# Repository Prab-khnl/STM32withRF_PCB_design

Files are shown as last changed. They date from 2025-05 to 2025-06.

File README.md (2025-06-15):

Chip used :- STM32WB55CEU6.

Important Online Note :-
<https://www.st.com/resource/en/application_note/an5165-how-to-develop-rf-hardware-using-stm32wb-microcontrollers-stmicroelectronics.pdf>

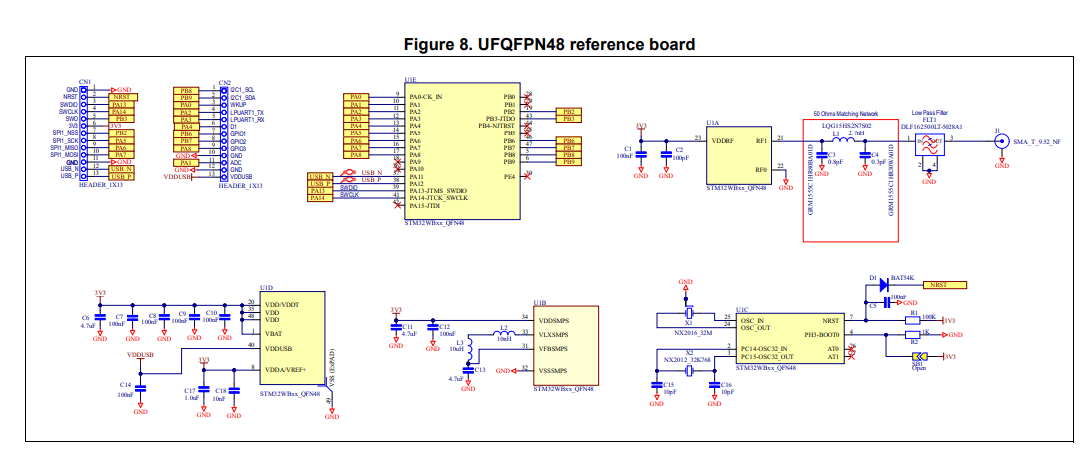
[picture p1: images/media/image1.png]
This is the reference :-

Use STM32CubeIDE to get more information about the Chip :-

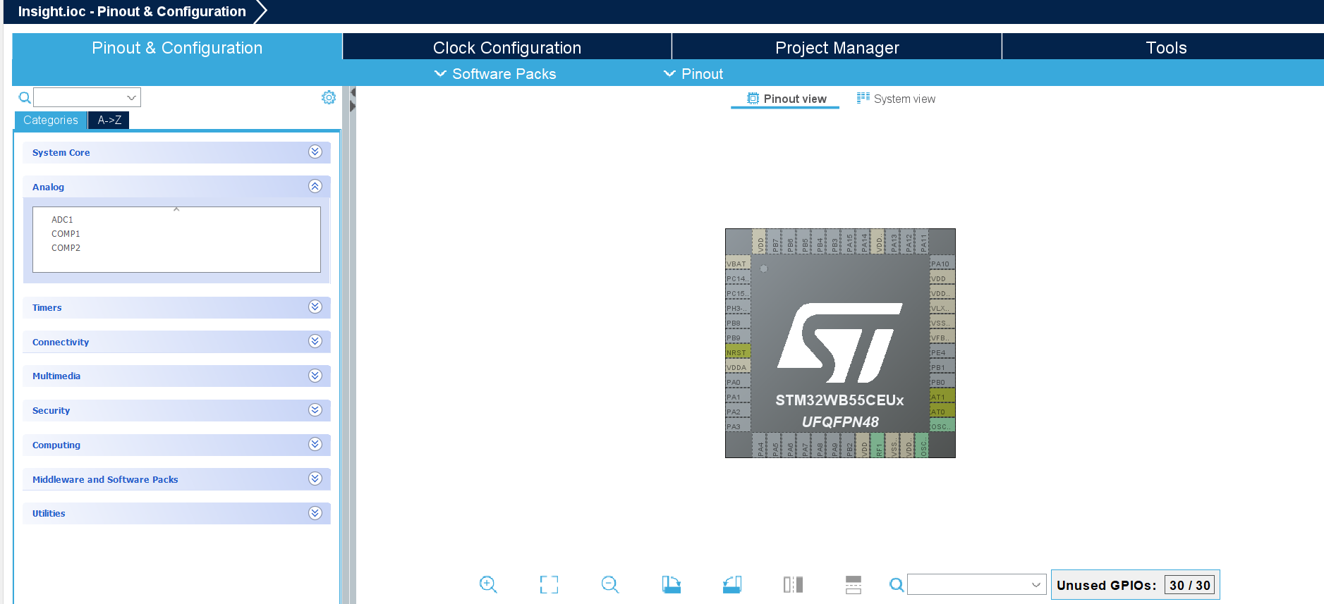
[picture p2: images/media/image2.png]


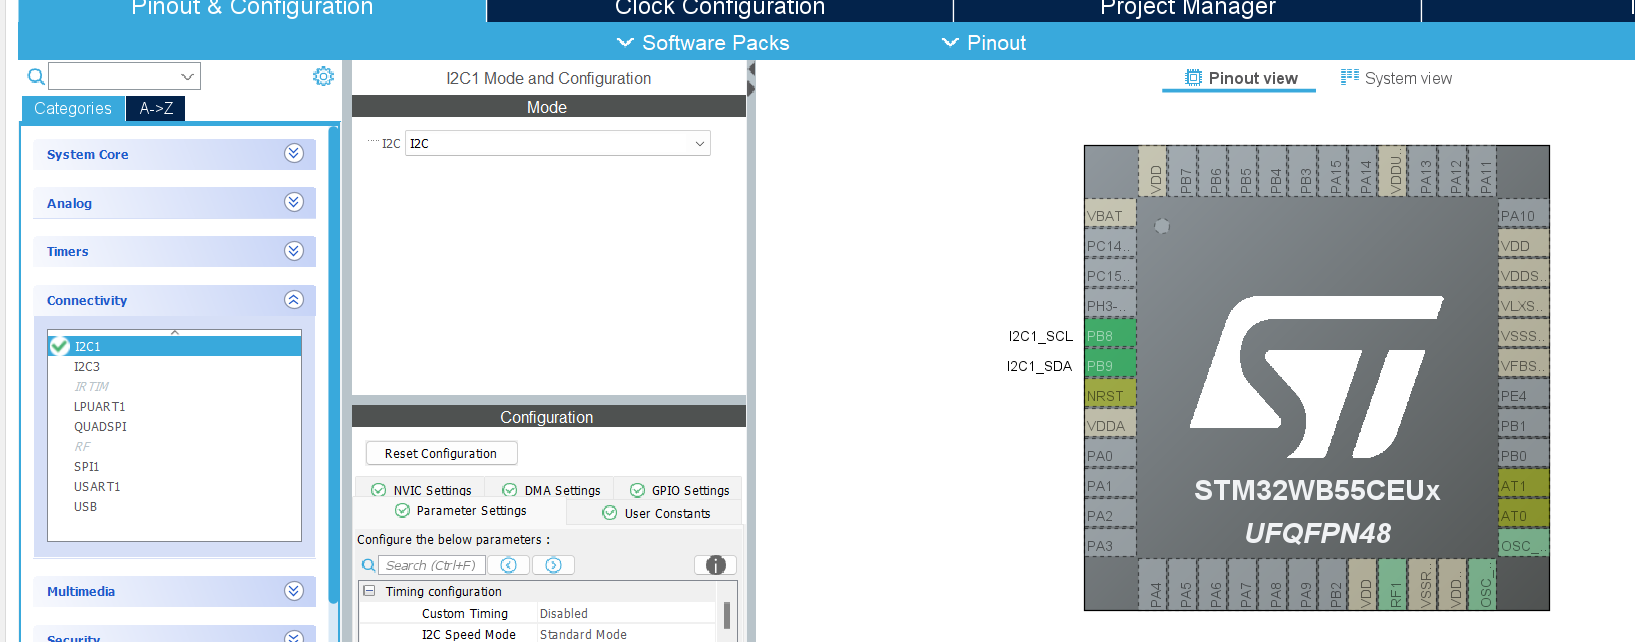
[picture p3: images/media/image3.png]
Here I have enabled I2C on PB8 and PB9
corresponding to Pin 5 and 6 respectively.

In Kicad, import the board STM32WB55CEUX.

Ground the Pins VSS5MP5, VSSRF and VSS.

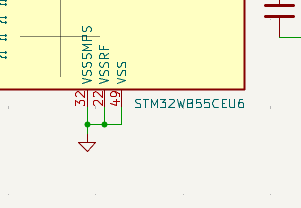
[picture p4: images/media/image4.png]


As illustrated on the reference manual, the Pin VDDUSB, VDDA, VDD, VDD,
VDD and VBAT are connected to 3.3V power supply through bigger capacitor
(4.67uF) and smaller capacitors (100nF : local supply).

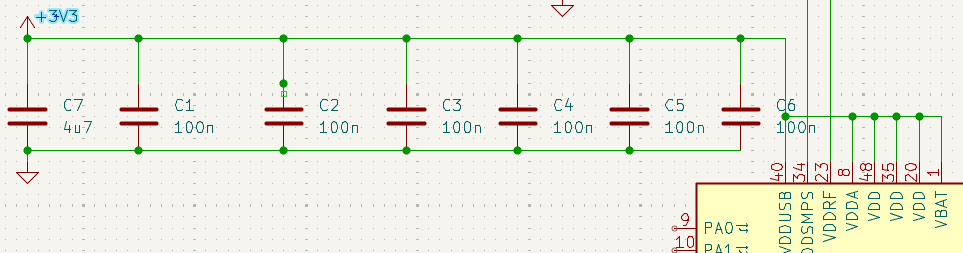
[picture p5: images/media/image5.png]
A screen shot of a graph AI-generated content may be incorrect.


For VDDRF, connect it to 100nF capacitor along with power supply

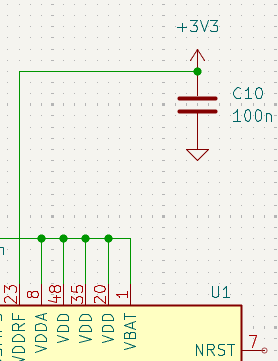
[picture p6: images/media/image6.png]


We need Stepdown converter to step down voltage for lower voltage. For 8
MHz we use 2.2uH inductor and for 4MHz we use 10uF inductor. SMPSLX --
Switch Mode Power Supply

SMPSFB -- Switch Power Supply Feed Back

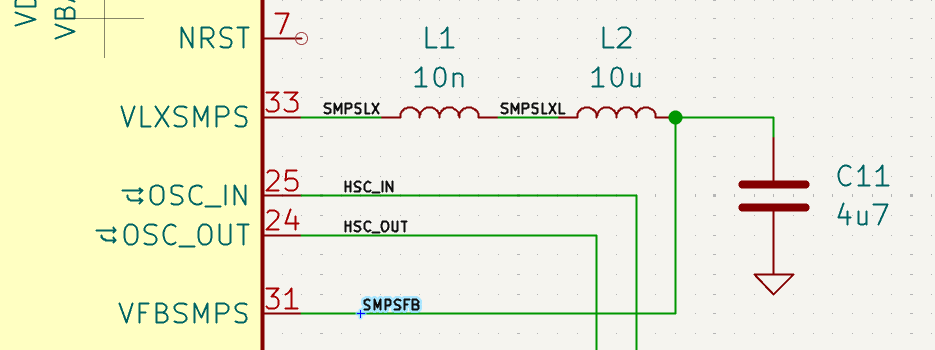
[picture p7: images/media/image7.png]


The low frequency oscillator(Crystal) is connected to Pin 2 and 3.

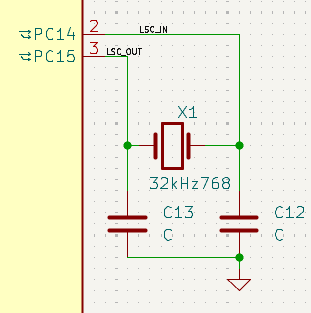
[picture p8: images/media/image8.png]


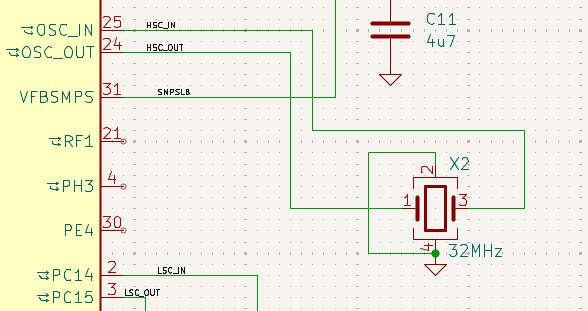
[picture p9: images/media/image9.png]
The high frequency
oscillator(Crystal_GND24) are connected to Pin 24 and 25.

We can add resistor in HSC_IN to increase the longevity of oscillator.

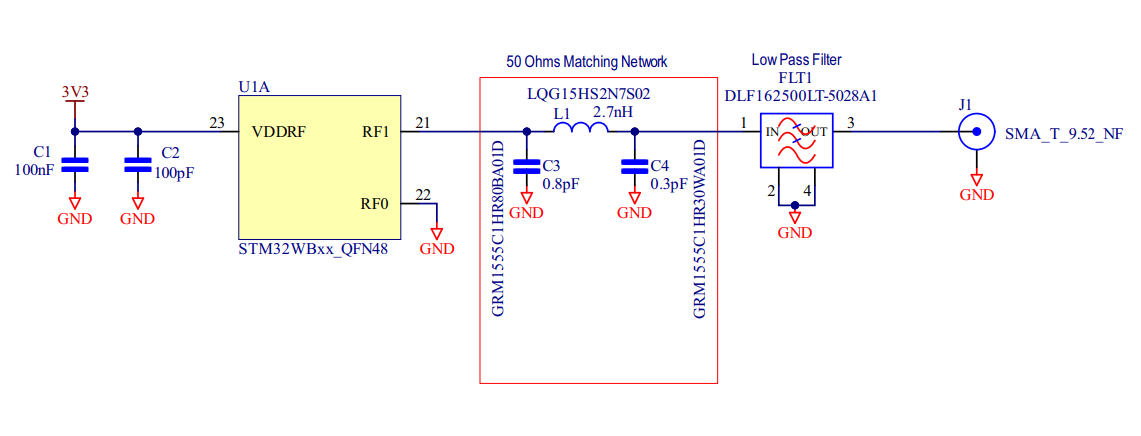
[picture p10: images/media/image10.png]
RF Section:-

We need low pass filter for 2.4GHz and 5GHz.

For that we need to create a footprint and symbol of DLF162500LT-5028A1.

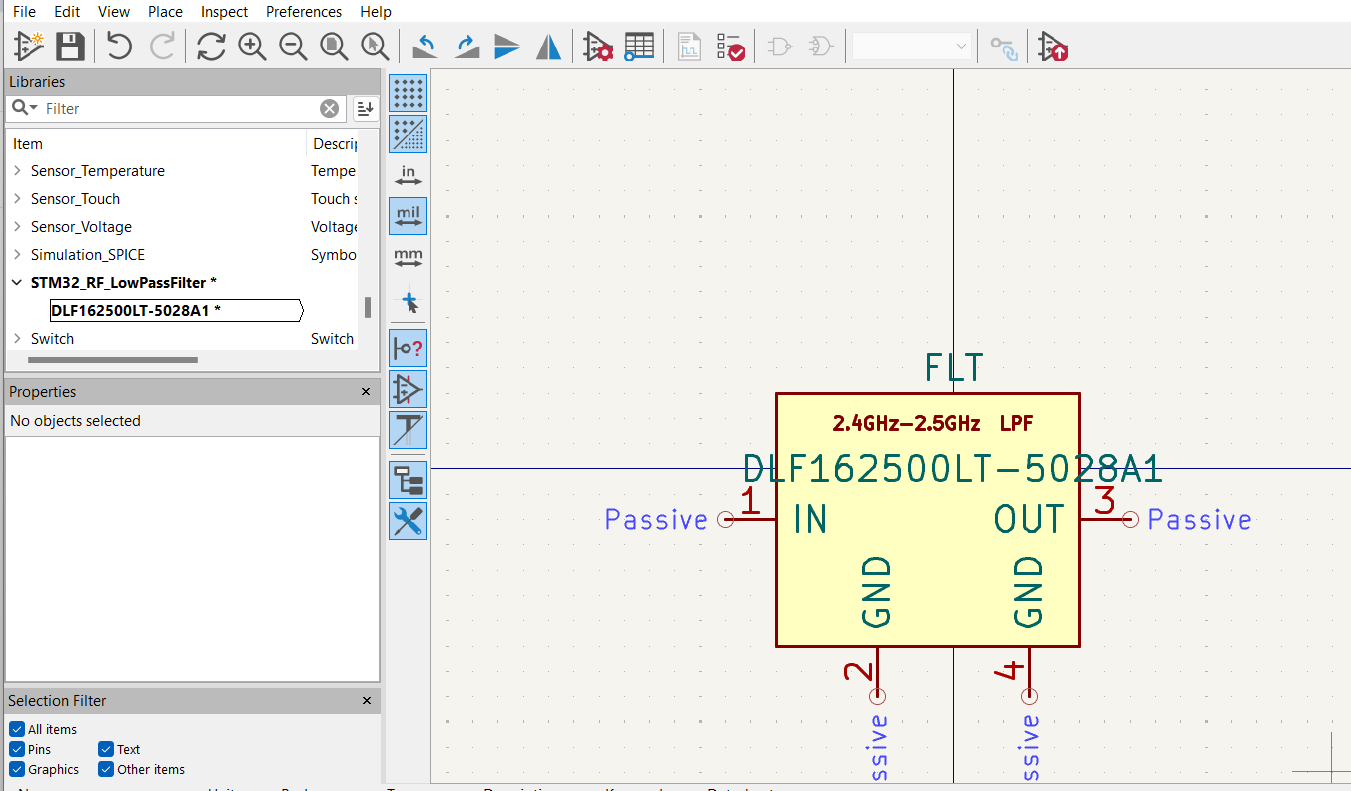
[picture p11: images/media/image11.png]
From File, Add library\> DLF162500LT-5028A1

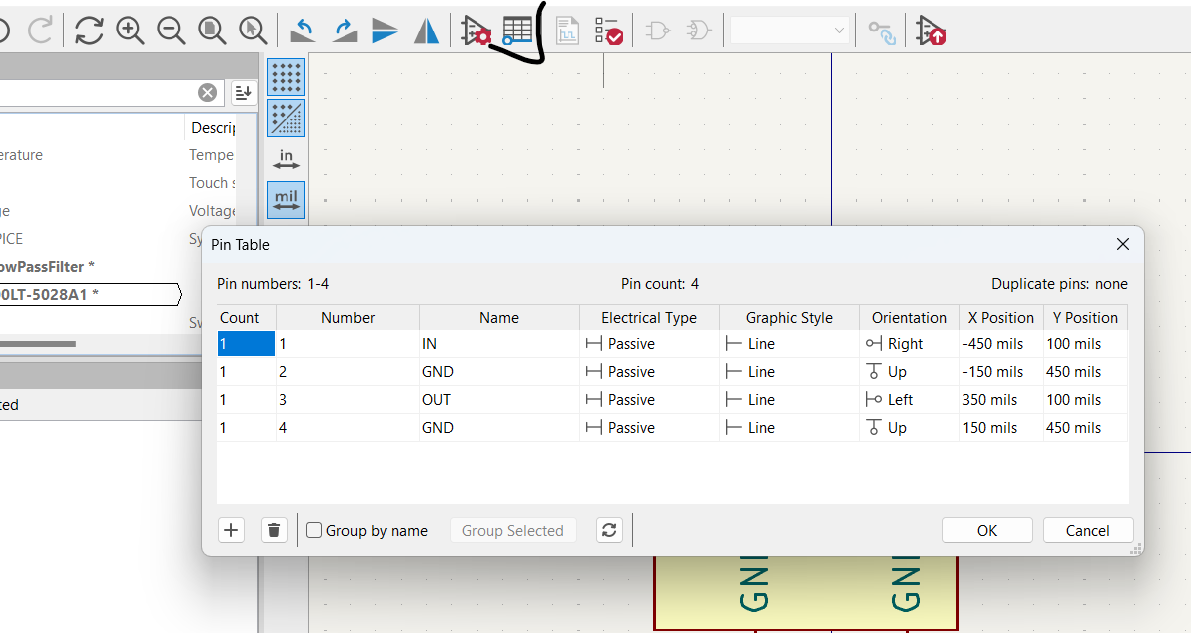
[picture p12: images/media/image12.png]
Go to the Pin table and add pins.

Use the rectangle tool on the right side to draw the rectangle touching
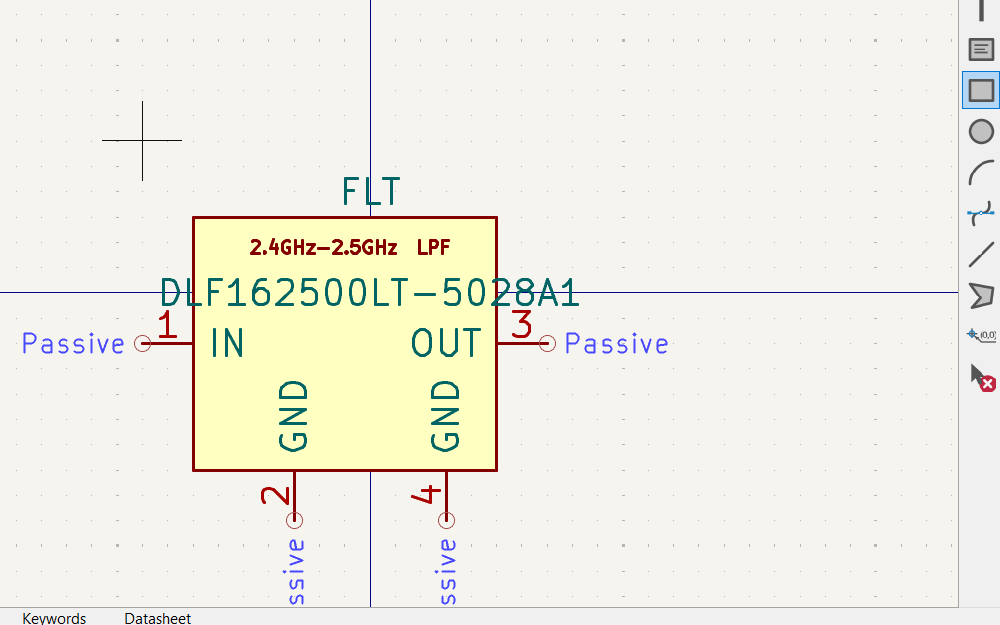
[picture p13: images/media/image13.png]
the pins.

Use the Text "T" tool to add the text label "2.4GHz- 2.5GHz".

Save the symbol. Now it's time to create the physical footprint of the
symbol.

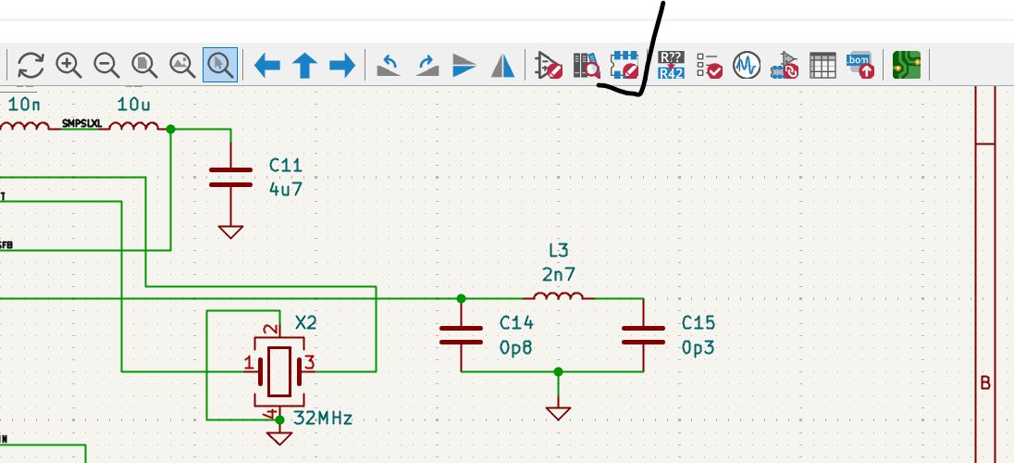
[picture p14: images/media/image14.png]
Use this footprint editor to create the new footprint.

Go to file \> Add library and name your library.

Here the newly added library is STM32_RF_LowPassFilterFootPrint

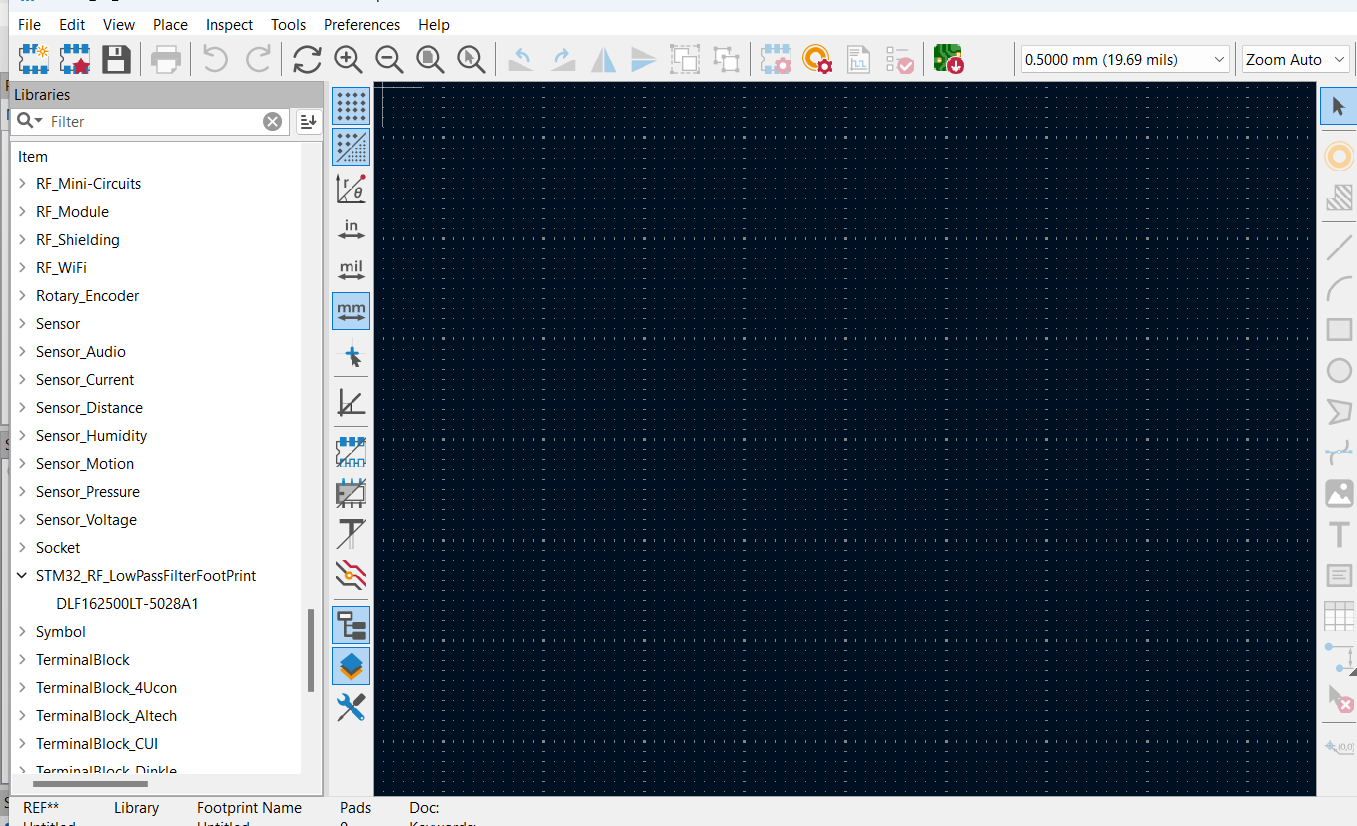
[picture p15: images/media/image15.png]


In the new library, add new Footprint and name it as Component name eg.
"DLF162500LT-5028A1"

This is the dimension of
[footprint](https://product.tdk.com/system/files/dam/doc/product/rf/rf/filter/catalog/rf_lpf_dlf162500lt-5028a1_en.pdf).

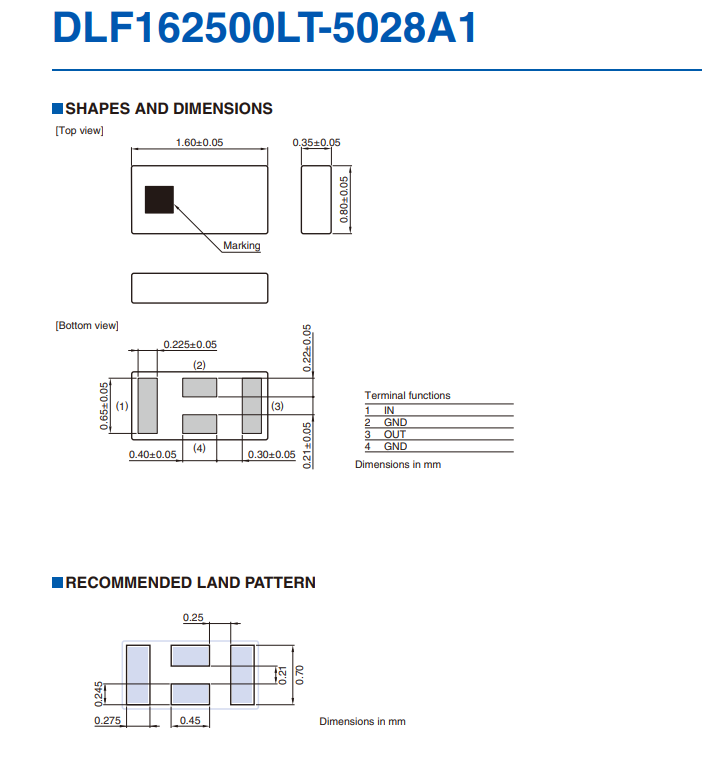
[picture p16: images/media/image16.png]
A blueprint of a diagram AI-generated content may be incorrect.


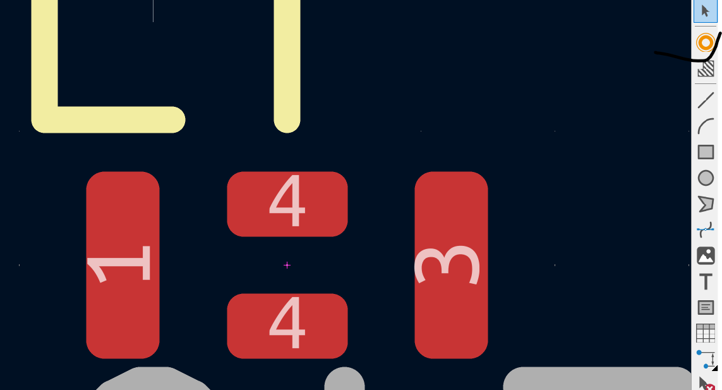
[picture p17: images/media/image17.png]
A screenshot of a phone AI-generated content may be incorrect.
Add pad from here.

According to the dimension, the centre of origin:-

X : ½ ( 0.275 + 0.45) + 0.25 = 0.6125.

Y : ½ (0.245 +0.21) = 0.2275

This is the position and dimensions of pad1 :-

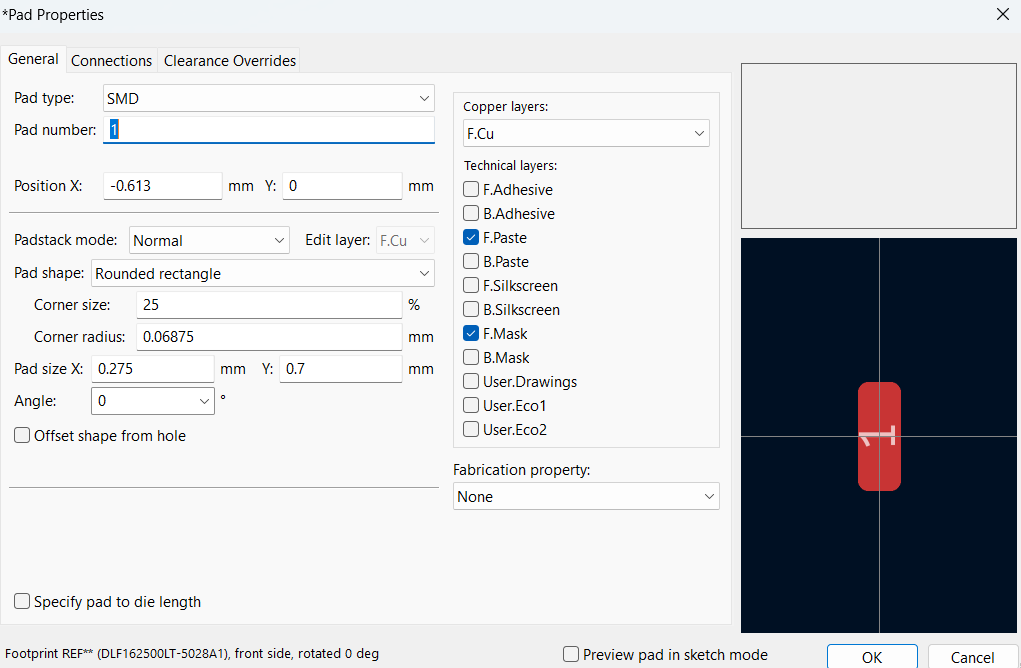
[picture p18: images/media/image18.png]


This is the position and dimensions of pad 3:-

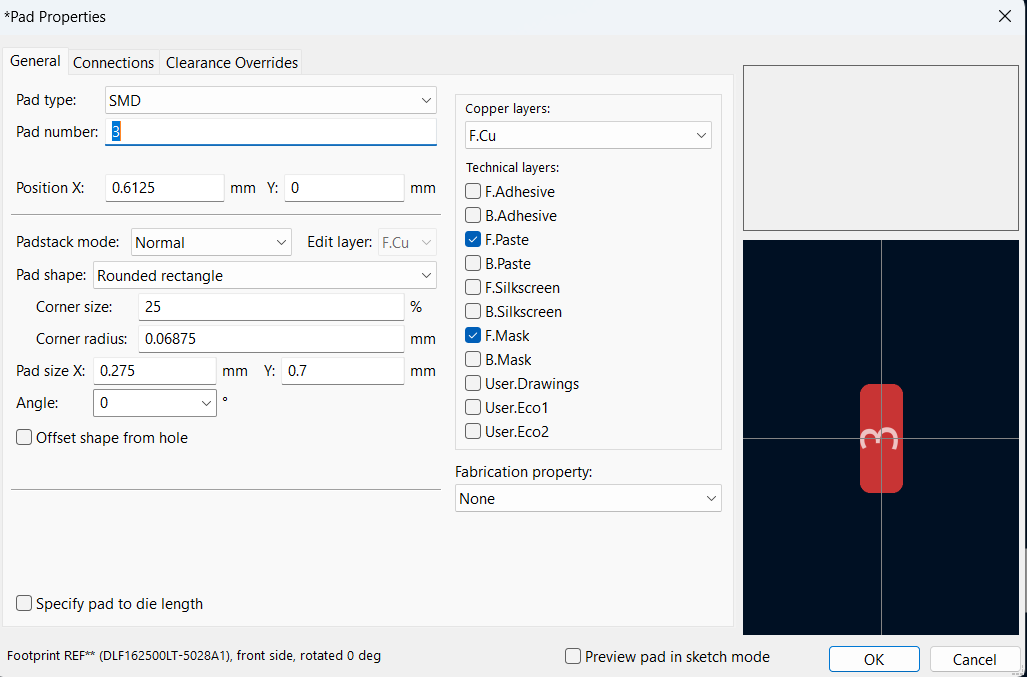
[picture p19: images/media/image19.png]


This is the position and dimensions of pad 2:-

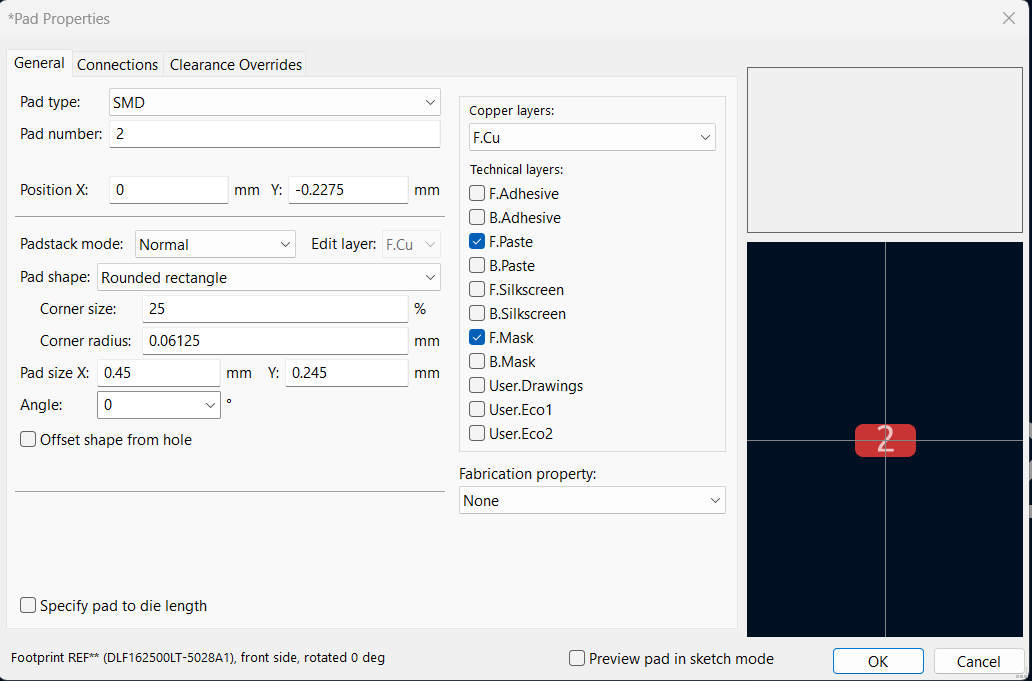
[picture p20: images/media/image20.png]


This is the position and dimensions of pad 4:-

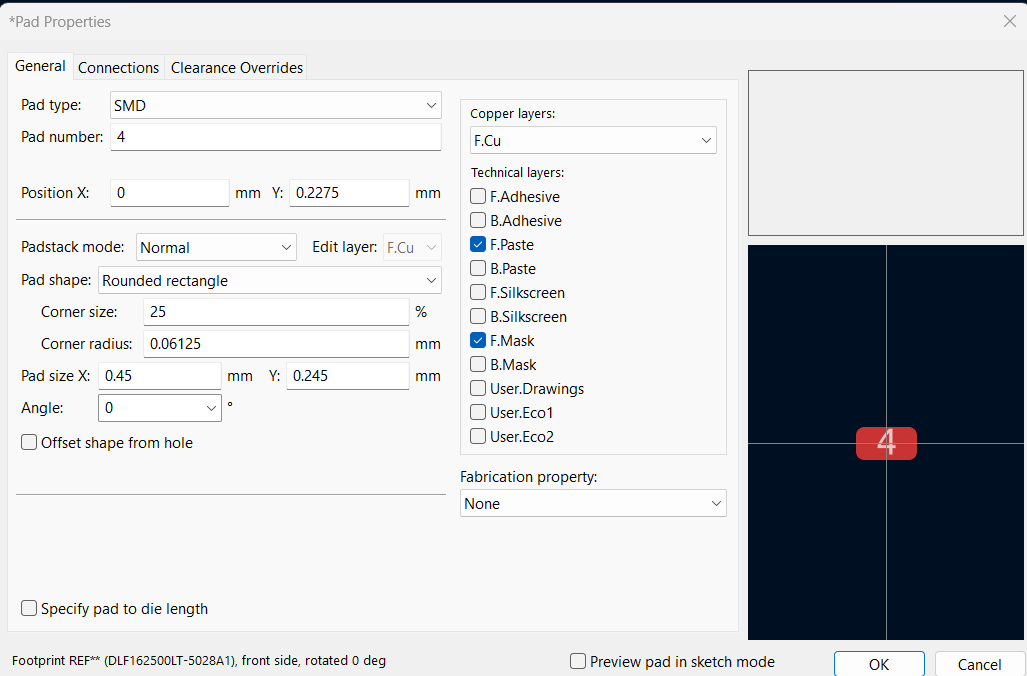
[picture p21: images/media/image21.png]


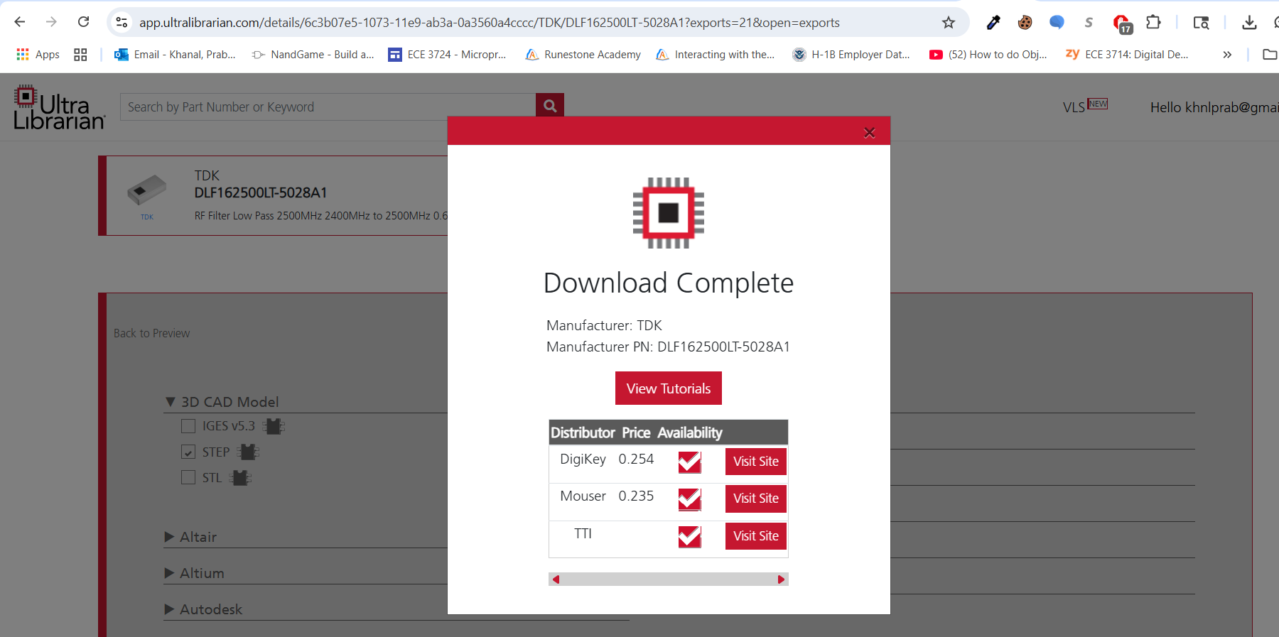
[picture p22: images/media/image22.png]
Download 3D Model of symbol from ultralibrarian in .step format.

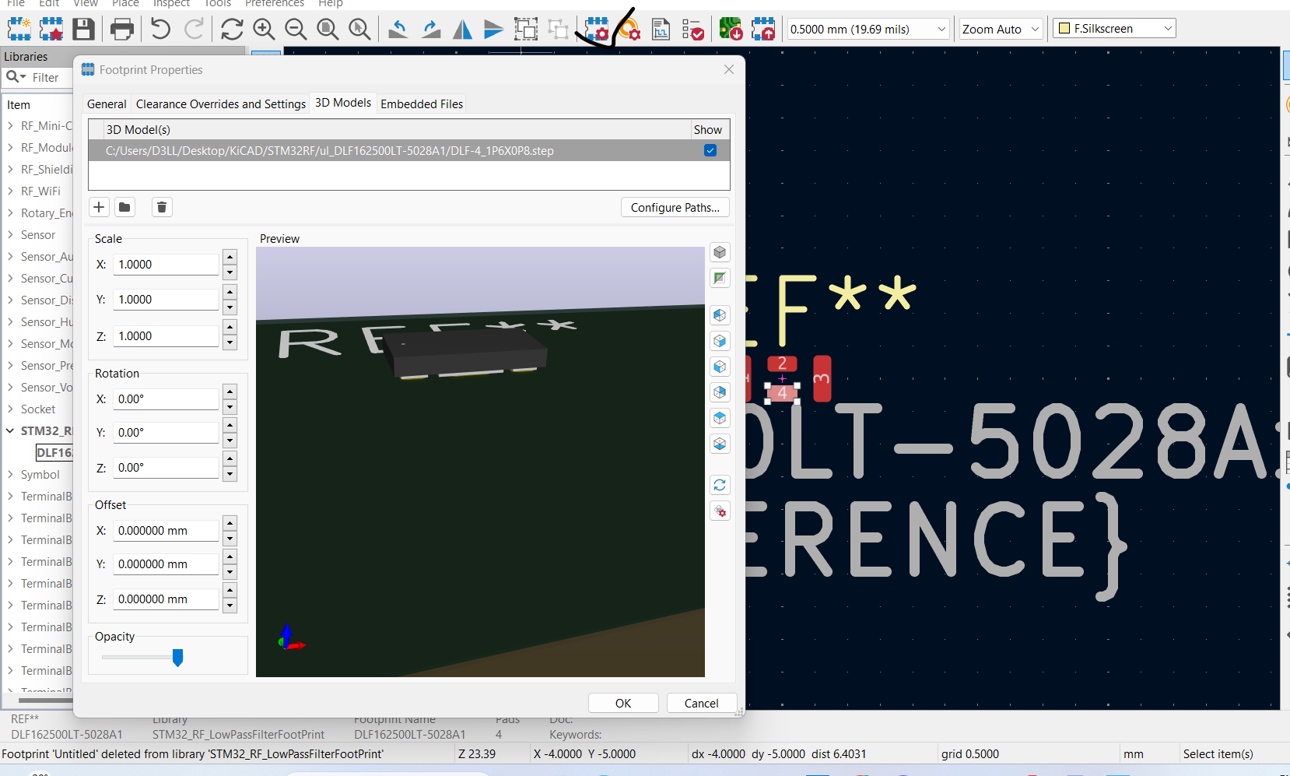
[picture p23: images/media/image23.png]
In Kicad go to footprint properties and
add the 3d model. Our pad aligns with physical pins.

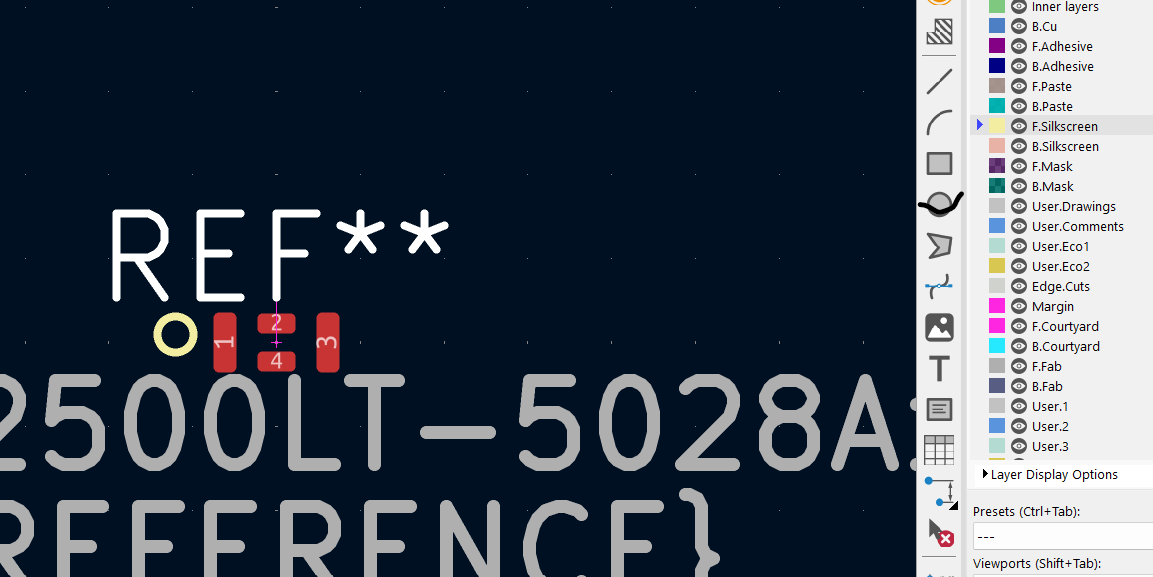
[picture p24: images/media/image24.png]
With silkscreen layer selected, click
circle tool to add indicator for pin 1.

Using the symbol editor, assign newly created footprint to the symbol we
just created.

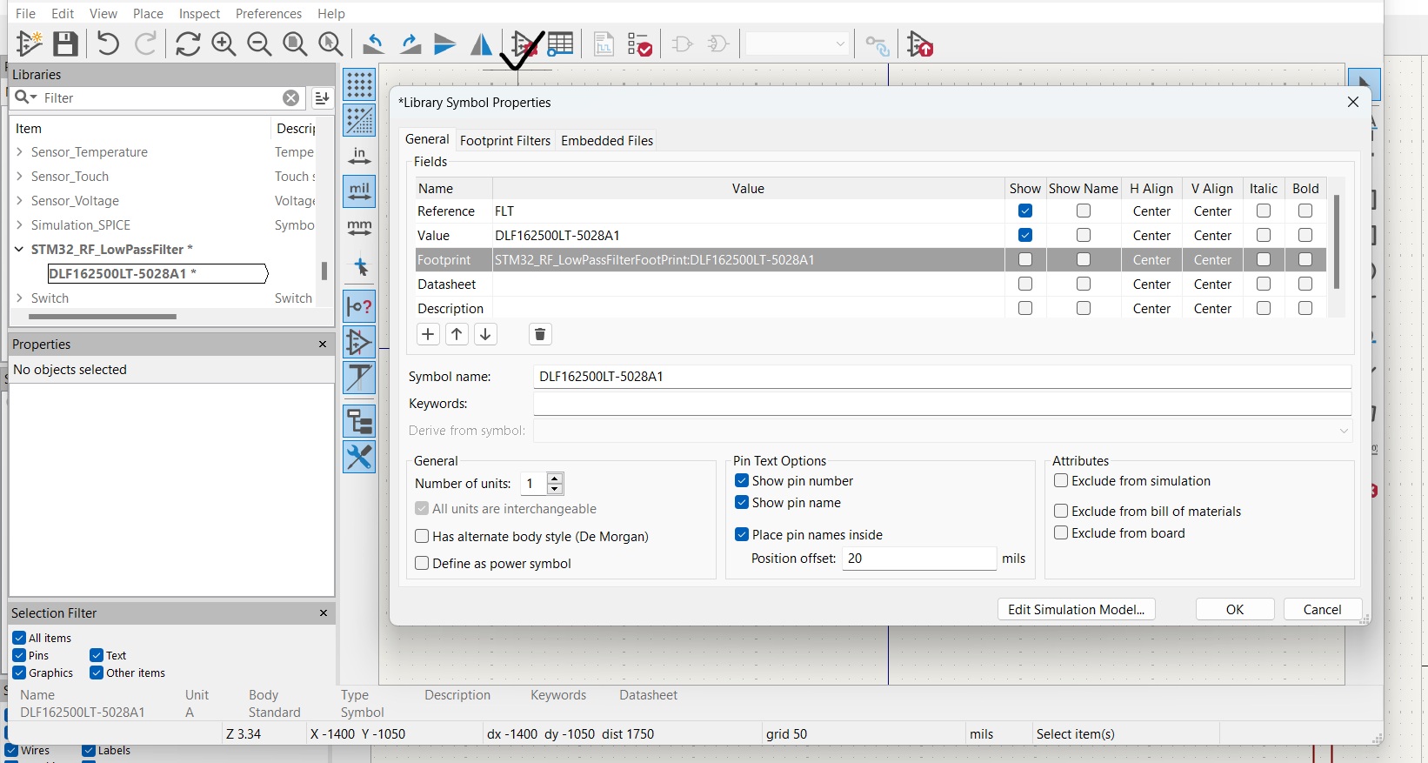
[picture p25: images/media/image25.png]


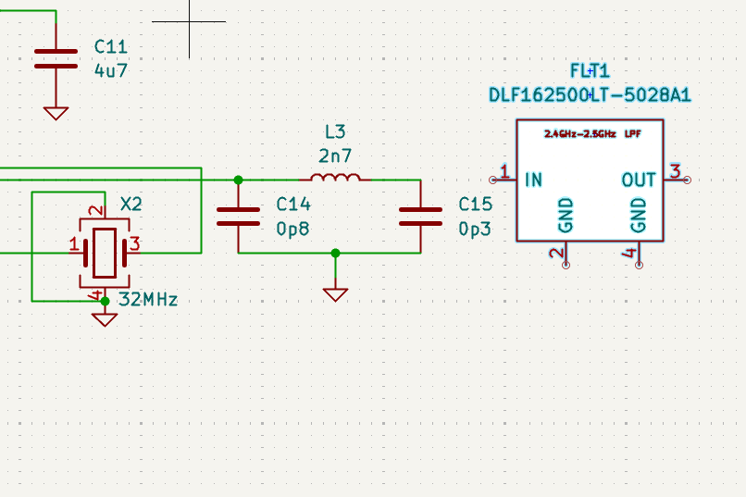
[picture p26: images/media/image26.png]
Place newly created symbol to the schematic and connect to pin 1.

Add a Co-Axial connector.

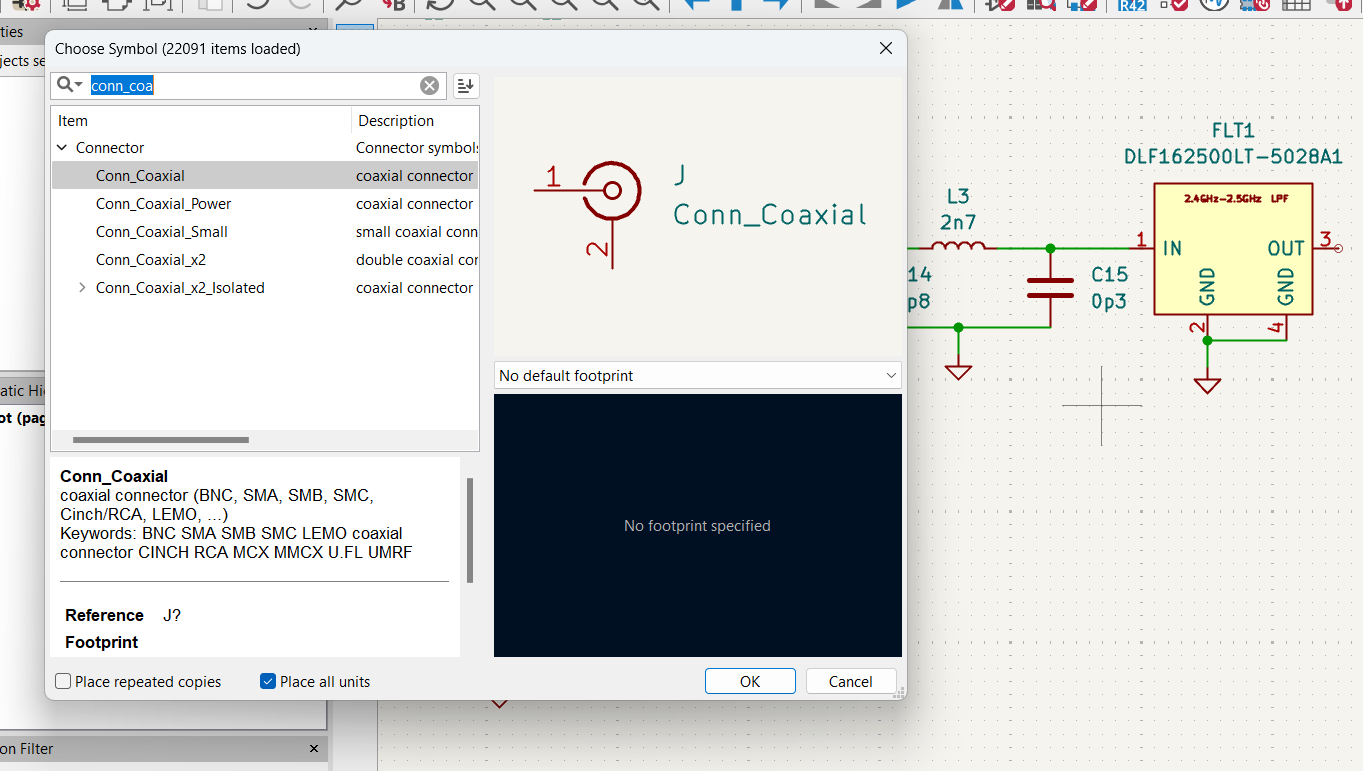
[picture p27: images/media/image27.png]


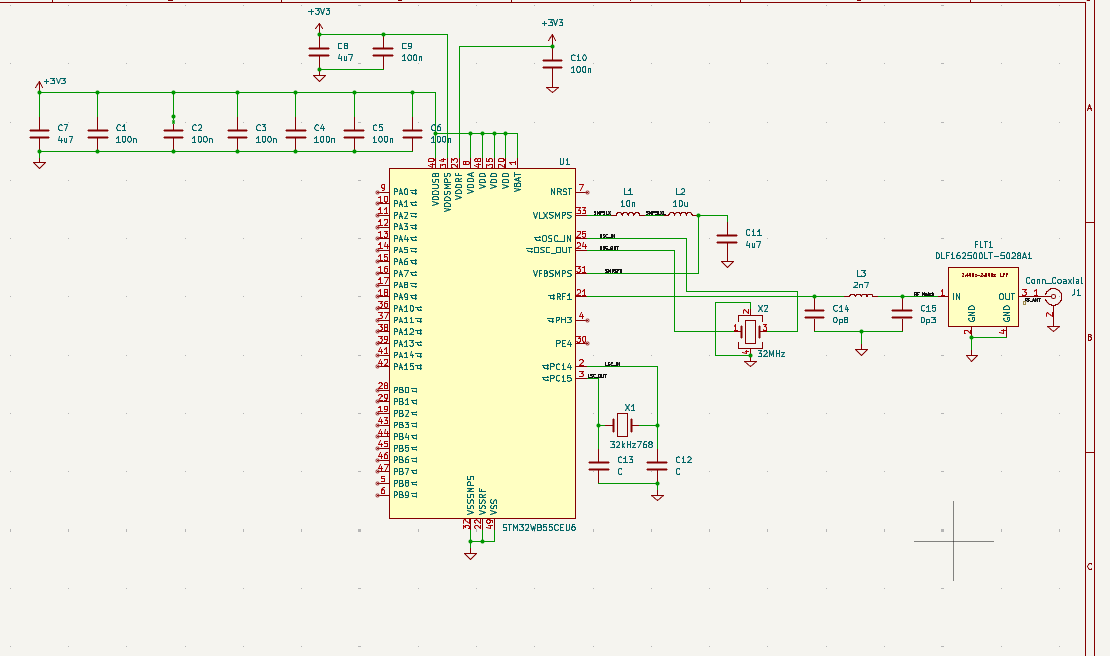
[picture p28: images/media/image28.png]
This is our current progress.

Now, we need to add the programming interface.

The PA 13, PA 14 and PA3 can be used to program and debug the board.
Along with those pins NRST has to be low (0) for programming mode and
high (1) on normal mode.

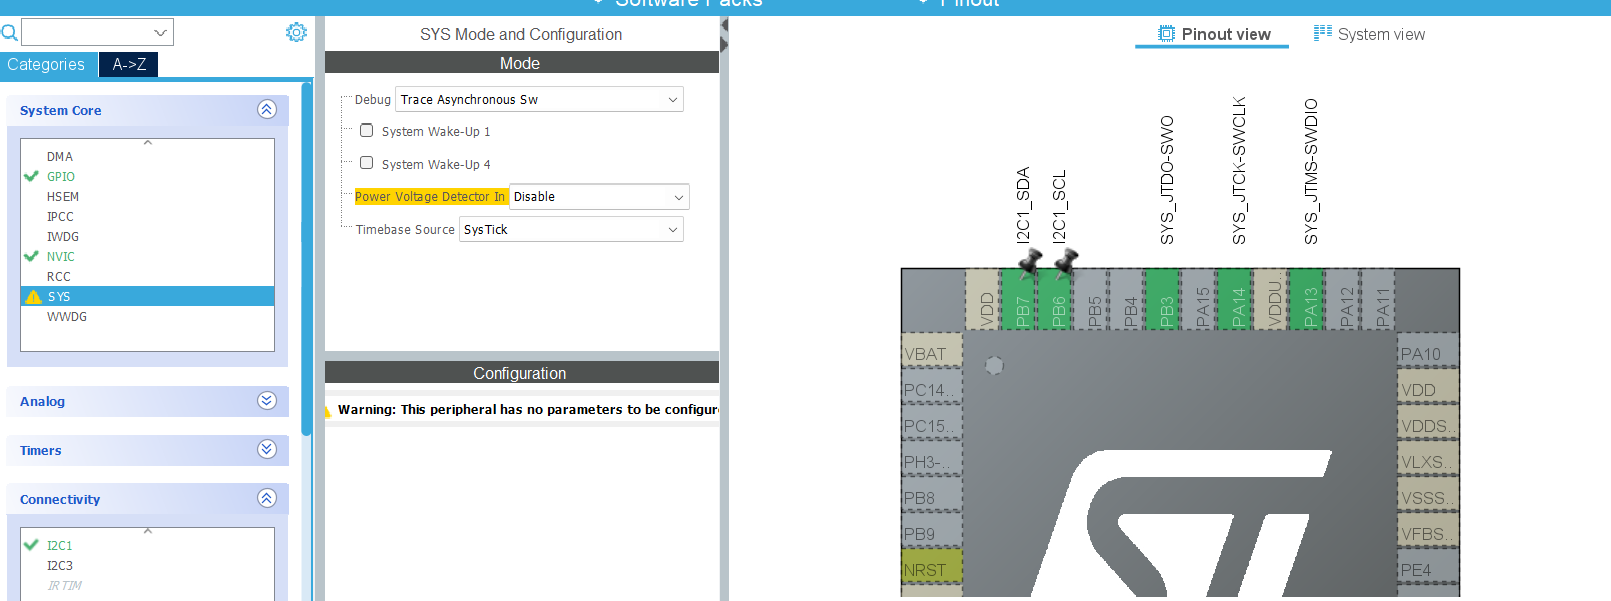
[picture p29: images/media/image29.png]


Connect the tag connector "Conn_ARM_SWD_TagConnect_TC2030". Connect the
tag connector to respective pin as shown. For NRST( Reset) pin connect
it through 100nF capacitor at Pin 7.

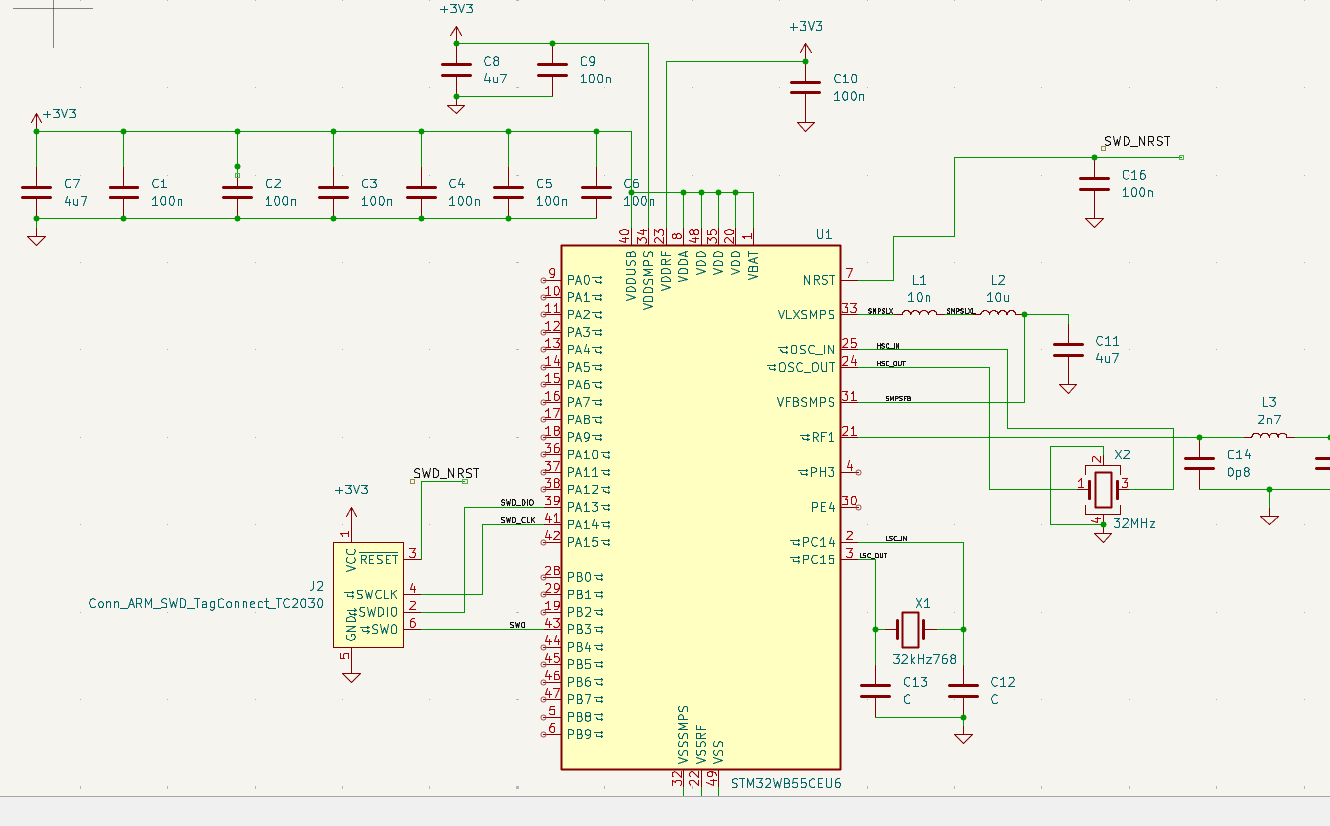
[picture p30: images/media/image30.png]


PH3 is bootload pin and should 0 be on bootload. When the pin Switch is
not pressed, the PH3 is grounded but on pressed, the connection acts as
lowpass RC filter.

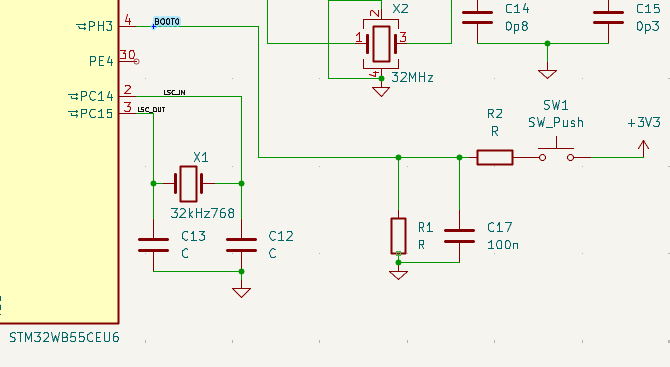
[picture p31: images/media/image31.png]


Add USB "USB_C_Receptacle_USB2.0_16P" and we are going to use pin 37 and
38.

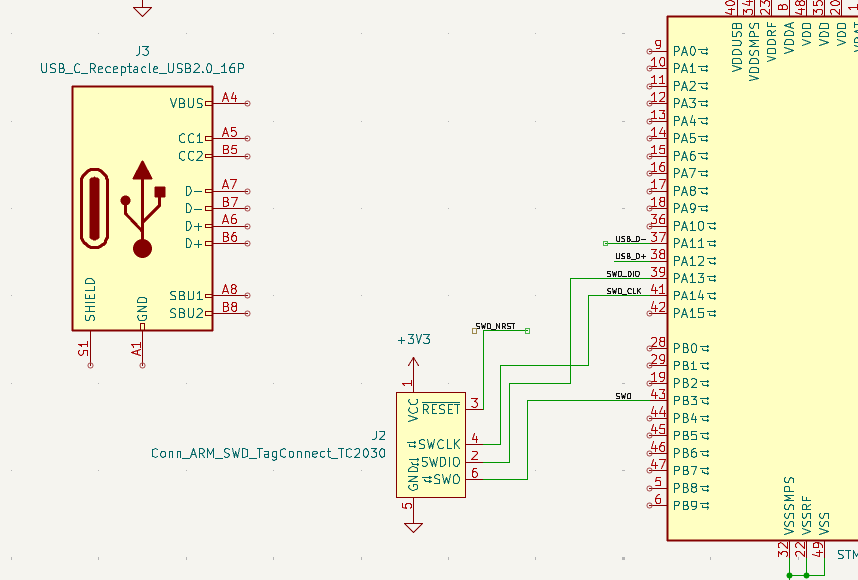
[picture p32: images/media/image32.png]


Add a USB protector between the USB Connector and Pins.

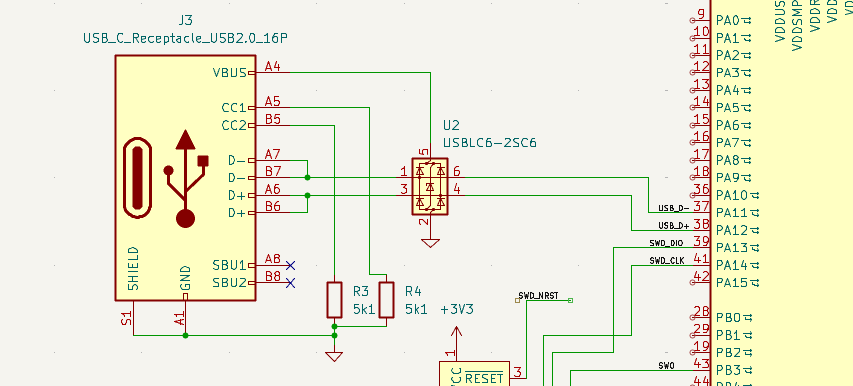
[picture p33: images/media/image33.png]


The D- pins and D+ pins are connected each other and then to Pins 1 and
3 respectively on the USB protector. The VBUS is connected to Pin 5. Pin
6 and 4 are connected to Pin 37 and 37 respectively on the STM32
Microcontroller.

The pull down resistors are tied on the Pin A5 and B5.

Convert 5V of VBUS to 3.3V using LDO voltage regulator.

Search LDO voltage regulator by putting requirement on mouser. Add a
voltage regulator "MIC5365-3.3YD5" to get 3.3V output.

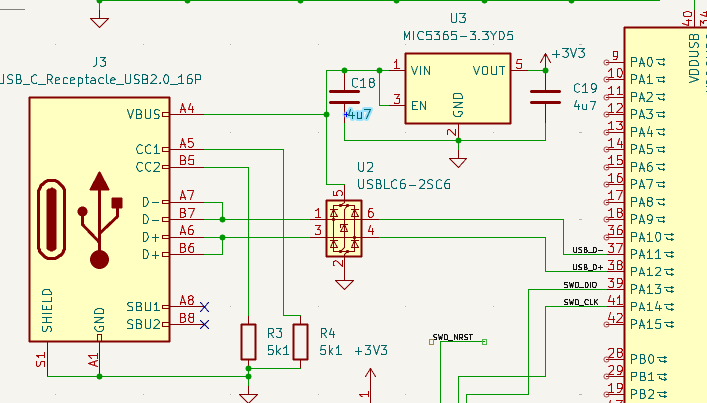
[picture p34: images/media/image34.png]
A computer circuit board with many wires AI-generated content may be incorrect.


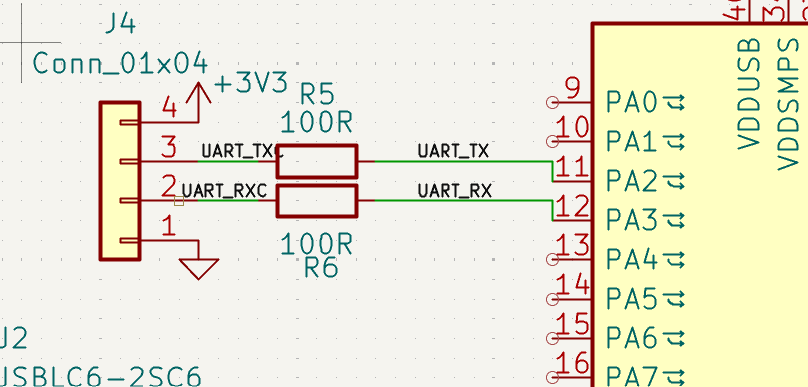
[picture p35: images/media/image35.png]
Add a Peripheral connection on PA2 and PA2
using Generic 01\*04 Connector.

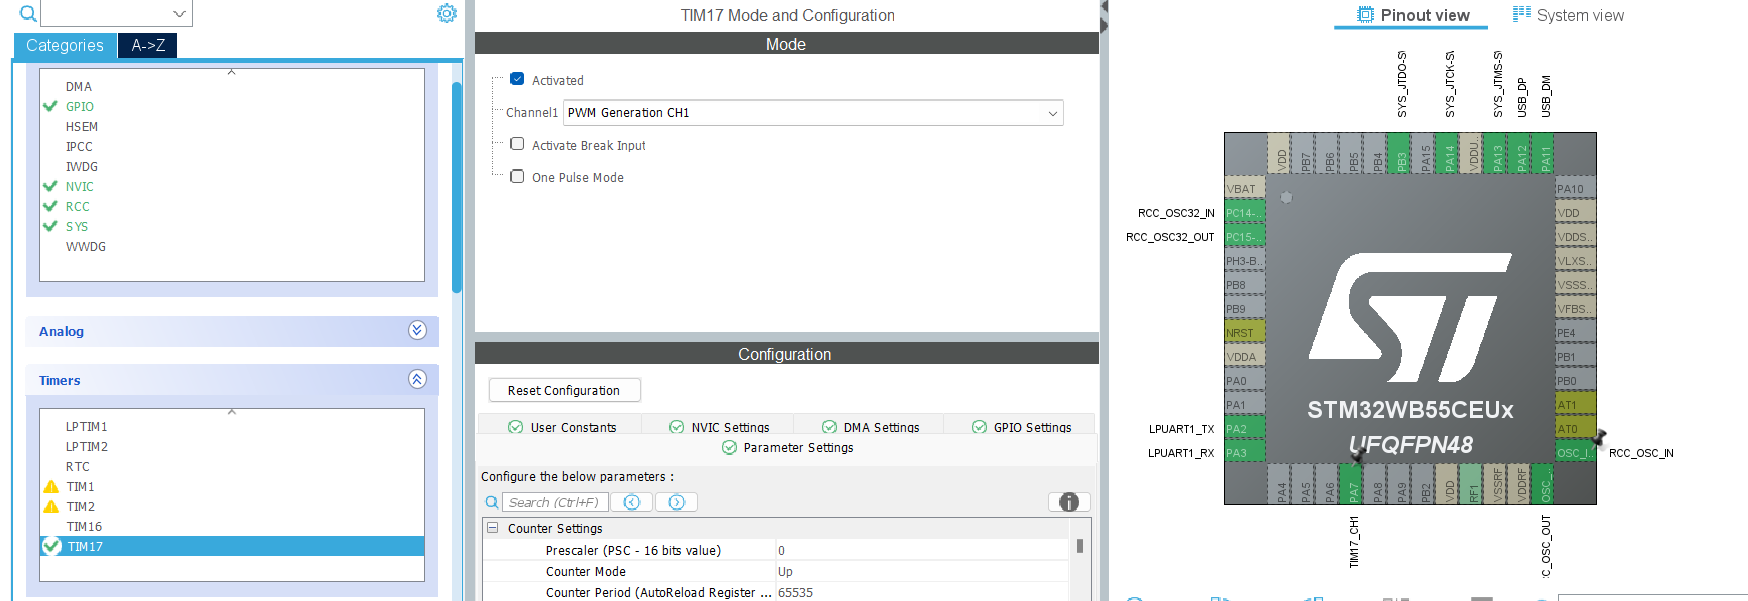
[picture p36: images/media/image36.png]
Use PA7 for PWM Output signal generation.

Add LED to Pin 16 (PA7) and add current limiting 220 Ohm resistor.

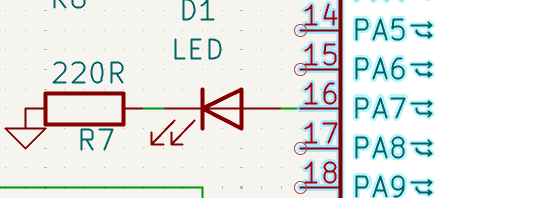
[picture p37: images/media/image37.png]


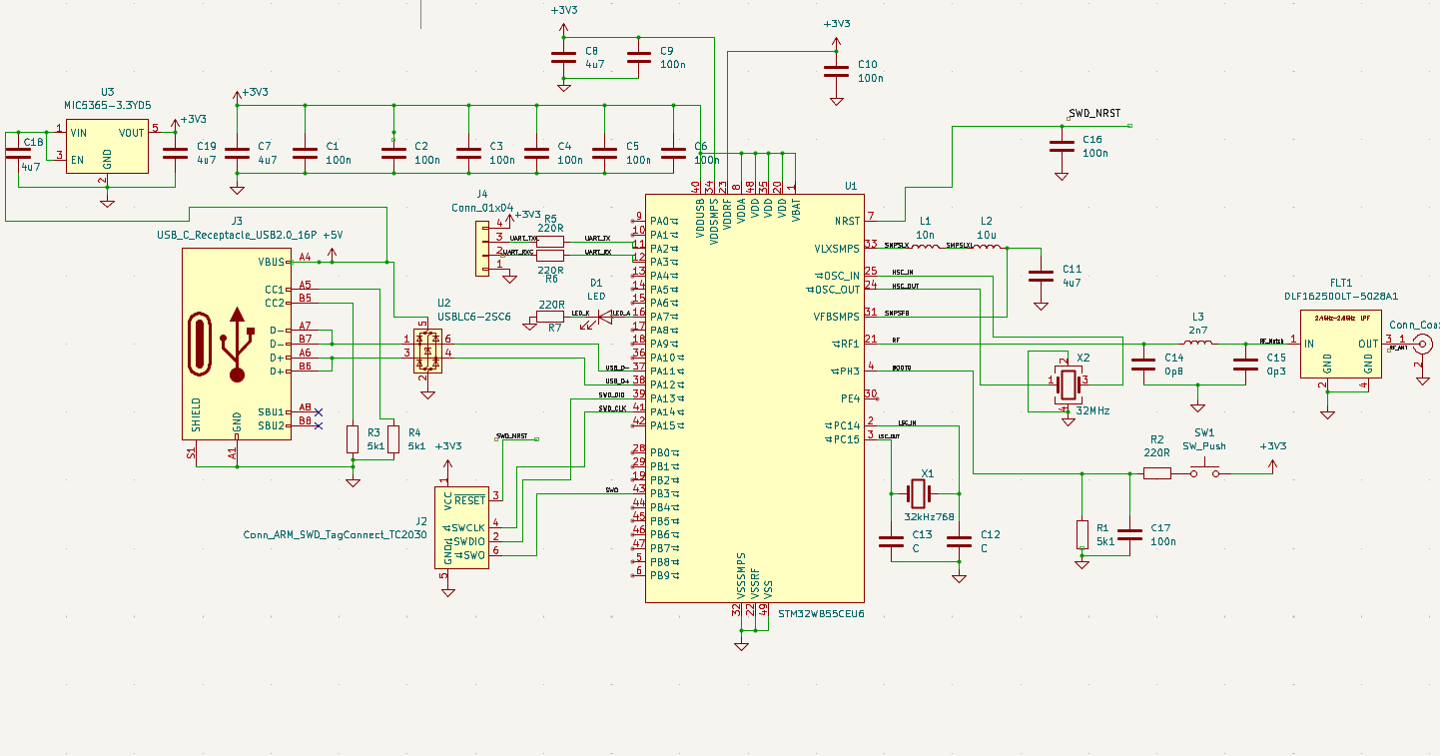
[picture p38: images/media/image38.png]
Overall schematic :-

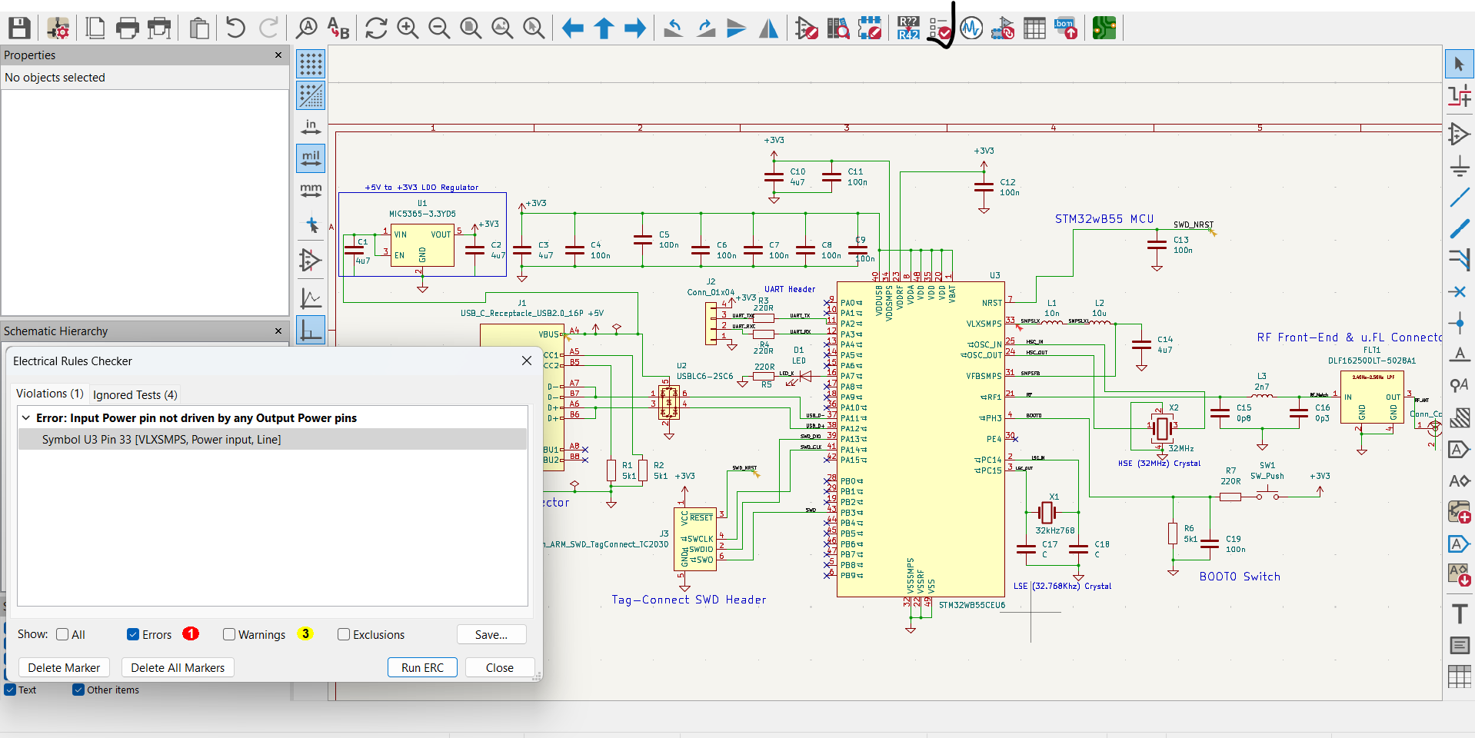
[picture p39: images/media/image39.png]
Run electric rule checker and make sure all
wirings are correct.

Add footprint to the capacitor.

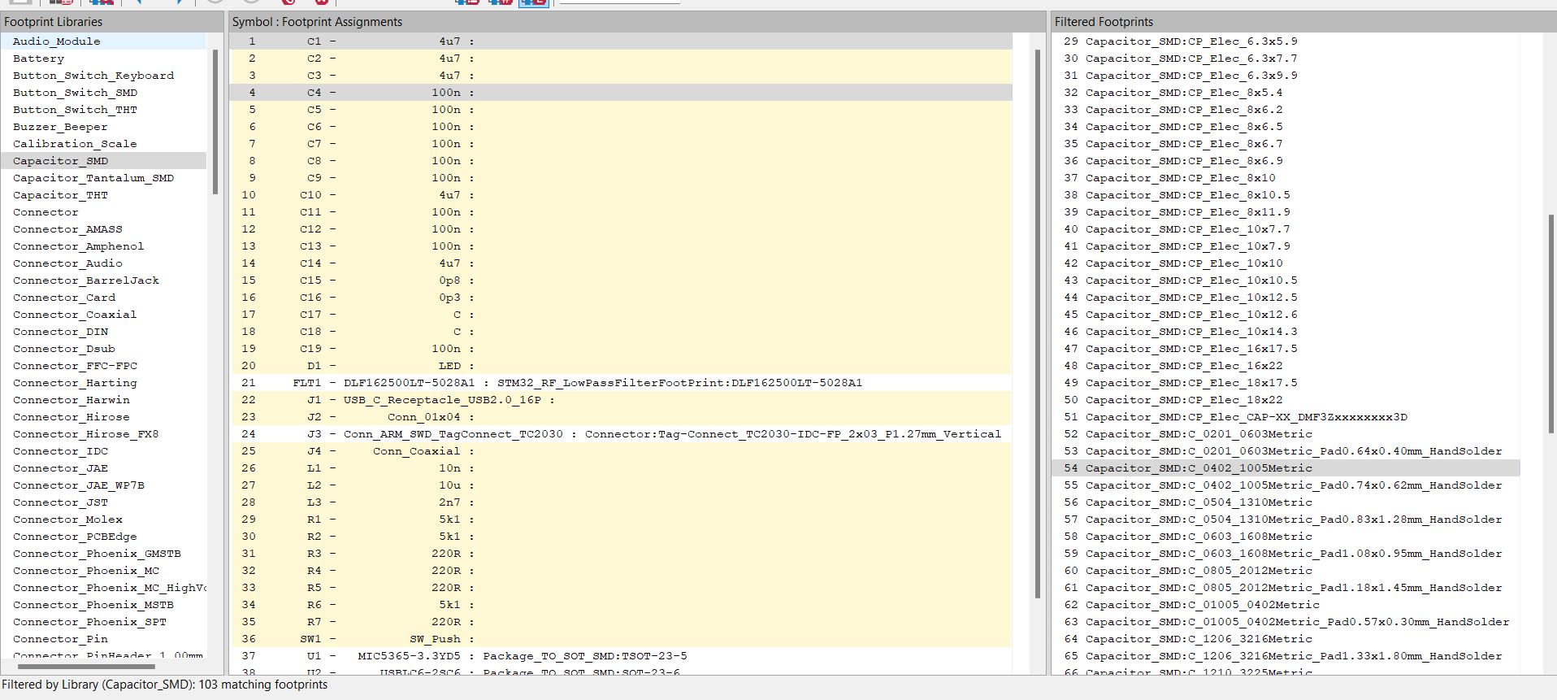
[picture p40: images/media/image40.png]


Add footprint to all the components.

A screenshot of a computer AI-generated content may be incorrect.

Create Bill of Materials for all the components.

A screenshot of a computer AI-generated content may be incorrect.

A screenshot of a computer AI-generated content may be incorrect.Add netclass to group the components.

Setup layers

A screenshot of a computer AI-generated content may be incorrect.

Select 4 layers and impedance controlled

A screenshot of a computer AI-generated content may be incorrect.

A screenshot of a computer AI-generated content may be incorrect.Select these layer width

Lead free copper

A screenshot of a computer AI-generated content may be incorrect.

Solder Mask

A screenshot of a computer AI-generated content may be incorrect.

A screenshot of a computer AI-generated content may be incorrect.Fill in these board capabilities and
requirements

A screenshot of a computer AI-generated content may be incorrect.Board rule

A screenshot of a computer AI-generated content may be incorrect.These tracks are calculated on 50 ohm
impedance.

Press Ok

Multi layer PCBA diagram of a layer of copper layer AI-generated content may be incorrect.

Press F8 to apply the footprints

A computer screen shot of a computer AI-generated content may be incorrect.This is the current 3D view:-

Update the 3D Model STEP file for J2 connector downloaded from
[MOLEX](https://www.molex.com/en-us/products/part-detail/530480410).

A computer screen shot of a computer AI-generated content may be incorrect.

Add 3D model for STM32 from
[here](https://gitlab.com/kicad/libraries/kicad-packages3D/-/blob/5.1.10/Package_DFN_QFN.3dshapes/QFN-48-1EP_7x7mm_P0.5mm_EP5.6x5.6mm.step)

A screenshot of a computer AI-generated content may be incorrect.

3d model can be downloaded from here:-

> 3D content central
>
> Grabcad

A screenshot of a computer AI-generated content may be incorrect.Select blue color for SWD routing

Select net colors to blue for all

A screenshot of a computer AI-generated content may be incorrect.Do the same all others

Create a layout

Select 1 mmm grid

A machine with colorful lights AI-generated content may be incorrect.Move the chip by moving around with M.

Move critical section first like RF, USB connector close to
microcontroller. Also keep crystal and power close to microcontroller.

Debug,BOOT0 , Reset, TX and RX are less critical. BI coupling capacitor
needs to be close .

A computer screen shot of a computer chip AI-generated content may be incorrect.Keep Connector to left of IC.

Place USB connector to left of tag connector and rotate as indicated.

A computer screen shot of a computer chip AI-generated content may be incorrect.

A computer screen shot of a computer AI-generated content may be incorrect.Place RF connector to right of IC and place
filter in between the IC and connector.

Place the crystal as indicated.

A computer chip with many colors AI-generated content may be incorrect.

A computer screen shot of a computer chip AI-generated content may be incorrect.Place the L1, L2 and C14 to top of IC for
now

Place UART connector and resistor to bottom of IC.

A computer chip with many different colors AI-generated content may be incorrect.

A computer screen shot of a computer AI-generated content may be incorrect.Place USB protector as shown

Place the RF components as shown

A screenshot of a video game AI-generated content may be incorrect.

A computer chip with many different components AI-generated content may be incorrect.This is the current 3D view

Place capacitor to crystal oscillator

A computer screen shot of a computer AI-generated content may be incorrect.

A computer screen shot of a computer AI-generated content may be incorrect.Finetune this SMP power supply layout.

Place RF decoupling capacitor close to Pad 23

A screenshot of a computer AI-generated content may be incorrect.

Place another capacitor for pin 20

A screenshot of a computer AI-generated content may be incorrect.

Place capacitor like this near pin 40 to make room to route trace for
Serial DIO

A computer chip with numbers and symbols AI-generated content may be incorrect.

Place decoupling capacitor for pin 34 and 35

A screenshot of a computer AI-generated content may be incorrect.

A computer chip with many different colored lights AI-generated content may be incorrect.Re arrange this section

Make a room for reset pin

A computer chip with many different colored lights AI-generated content may be incorrect.

A computer screen shot of a computer chip AI-generated content may be incorrect.Move SMP close to microcontroller but put crystal
away

A screenshot of a video game AI-generated content may be incorrect.Place LDO 3.3V regulator as shown

Place resistors around USB C connector

A computer screen shot of a computer AI-generated content may be incorrect.

Place reset capacitor C13

A computer chip with many different colors AI-generated content may be incorrect.

Place the switch and resistors around the switch

A computer screen shot of a computer AI-generated content may be incorrect.

A computer chip with many different components AI-generated content may be incorrect.This is the current 3D layout of the board

A computer screen shot of a computer program AI-generated content may be incorrect.Define board out line. Select Edge.cuts
layer. Select line tool and draw the line.

You can also use the arc tool to draw the arc around the edge of the
board

A screen shot of a computer AI-generated content may be incorrect.

Start routing with most critical component. We can use top layer for
power and bottom layer for ground.

Signal -- GND -GND -Signal ( 4 layers) GNB Layer in Inner 1 and Inner 2

A screenshot of a computer AI-generated content may be incorrect.Select In1.Cu. Add a GND Layer and adjust
the electrical properties.

Draw outline of the board. Select B to fill the board.

A computer screen shot of a circuit board AI-generated content may be incorrect.

Add a mounting hole with this footprint.\
A screenshot of a computer AI-generated content may be incorrect.

Add fiducial marker to automate assembly.

A screenshot of a computer AI-generated content may be incorrect.

A computer screen shot of a computer AI-generated content may be incorrect.Place the mounting hole and marker as
shown.

Use Via to jump between layer 0.7mm/0.33mm via

A screenshot of a computer AI-generated content may be incorrect.

A screenshot of a computer AI-generated content may be incorrect.Connect the via and track with GND Pad

Copy and paste these tracks and via on 0402 components.

A computer screen shot of a computer chip AI-generated content may be incorrect.

Place the via on the chips for heat sinking purpose.

A green screen with white text AI-generated content may be incorrect.

A computer screen shot of a computer chip AI-generated content may be incorrect.Add 3.3V via

For RF trace we would use 0.190mm trace for control impedance of 50 Ohm

A screenshot of a computer AI-generated content may be incorrect.Set the width of RF in NetClass properties.

A computer screen shot of a computer AI-generated content may be incorrect.Route the RF section

Route the high frequency HSC clock.

A computer screen shot of a circuit board AI-generated content may be incorrect.

A computer screen shot of a circuit board AI-generated content may be incorrect.Trace Low frequency clocks

Add 0.250 mm track width for Switch Model. Press W to increase the mad
width.

A screenshot of a computer AI-generated content may be incorrect. We can also use this for the feedback

Ground the Pin

A screen shot of a computer AI-generated content may be incorrect.

Use differential pair by pressing 6 and selecting the netclass "USB" to
route the two usb wires together

A screenshot of a computer AI-generated content may be incorrect.Route the rest

A computer screen shot of a circuit board AI-generated content may be incorrect.

A screenshot of a computer AI-generated content may be incorrect.Route the UART Section

A computer screen shot of a circuit board AI-generated content may be incorrect.Use Via to jump between top and bottom
layer to route the Boot0

A computer screen shot of a computer AI-generated content may be incorrect.We can place the GND via near transitional jump for
higher bandwidth circuit

A computer screen shot of a circuit board AI-generated content may be incorrect.Complete the rest of the USB connector section.

Complete the led section

A screenshot of a video game AI-generated content may be incorrect.

Select Mounting hole. Select 2 and Press E to change the copper zones to
Solid

A screenshot of a computer AI-generated content may be incorrect.

A computer screen shot of a circuit board AI-generated content may be incorrect.Connect the 5Vs power supply traces and
draw polygon layer for 3V power supply.

A computer screen shot of a star AI-generated content may be incorrect.Select only the bottom select by selecting
"Hide all planes but active" and draw traces connecting 3.3V Vias

The other way to do is to convert the bottom layer polygon to 3.3V
layer. For that select the GNB polygon, Crl +C and paste it. Press E to
select the new layer and select 3.3V for bottom layer

A screenshot of a computer AI-generated content may be incorrect.

A screenshot of a video game AI-generated content may be incorrect.Now, 3.3V is the bottom layer.

A computer screen shot of a computer chip AI-generated content may be incorrect.Connect rest of the 3.3V and GNB
connections

For copper balancing, change the top copper layer to GND. To do this
Select In1.cu and double click on GND layer. Choose F.CU to GND Layer.

A screenshot of a computer AI-generated content may be incorrect.

Press B to repull and now we have GND layer on top layer.

A computer screen shot of a circuit board AI-generated content may be incorrect.

These coppers which are really close could affect the impedance for the
RF section. The traces should be at least 3 times the dielectric width
away.

A video game screen with a green background AI-generated content may be incorrect.

Currently the dielectric is 0.1mm. We want the separation to be at least
0.3mm.

A screenshot of a computer AI-generated content may be incorrect.

Draw keypad area to keep out the copper fills.

A screenshot of a computer AI-generated content may be incorrect.

Press B to keep out the copper fills.

A screenshot of a video game AI-generated content may be incorrect.

A screenshot of a computer AI-generated content may be incorrect.Instead, we can also change the clearance
to 0.35mm.

A screenshot of a computer AI-generated content may be incorrect.We can also try thermal relief to have
smaller gap and larger spoke width.

We need to Stitching via to reduce impedance between ground plane and
vias. Place it around the board. The spacing can be calculated as

(3 \* 10\^8)/ (20\* sqrt(4.29) \*2.4\*10\^9) \*10\^3

Speed of light / 20 \* Sqrt of dielectric constant \* Frequency

=3mm

A computer screen shot of a circuit board AI-generated content may be incorrect.

A green circuit board with many small chips AI-generated content may be incorrect.This is what the board looks like

Move the marking on the silkscreen so that the markings do not overlap.

A computer screen shot of a computer chip AI-generated content may be incorrect.

We can add teardrops for smooth transition between wide and narrow
traces. Else, go to tools\> Remove unused pads

A screenshot of a computer AI-generated content may be incorrect.

Run DRC Checker.

Fix clearance violation by decreasing the pad size.

A screen shot of a computer AI-generated content may be incorrect.

Reduce the pad size in X axis.

A screenshot of a computer AI-generated content may be incorrect.

To solve this error, uncheck the fiducial marker pad from F.Cu.

A screenshot of a computer AI-generated content may be incorrect.

To fix it, connect the pad to GND via.

Uploaded image

Clearance violation

A screenshot of a computer AI-generated content may be incorrect.

Move the GND via.

A computer screen shot of a green and red line AI-generated content may be incorrect.

Now, we have 0 DRC violation

A computer screen shot of a computer AI-generated content may be incorrect.

Final Board:-

A computer screen shot of a green circuit board AI-generated content may be incorrect.

Go to Tools \> Generate Bill of Materials to generate the components
needed and their designator values on the PCB.

A screenshot of a computer AI-generated content may be incorrect.

We need to know the coordinate of the components to know where the
components are on the PCB.

At the Place \> Grid Place Origin and Drill Place Origin, put the origin
to bottom left.

A green screen with black dots and white text AI-generated content may be incorrect.

Go to files \> Fabrication Output \> Generate Placement files

A screenshot of a computer AI-generated content may be incorrect.

.pos file will appear on the project directory.

We now need the Gerber files. Go to files \> Fabrication Output \>
Generate Gerber files. Include the following layers and options.

A screenshot of a computer AI-generated content may be incorrect.

Go to generate layers and generate drill files.

You can check the gerber files using Kicad Gerber viewer. These are the
files we need to upload to manufacturer ( Gerber, Position files and
Bill of Materials). We can also send additional notes such as Control
Impedance, clearance and so on.

A computer screen shot of a computer AI-generated content may be incorrect.

To order the PCB, create and upload zip files of Gerber.

A screenshot of a computer AI-generated content may be incorrect.

It automatically identified the board requirements

A screenshot of a computer AI-generated content may be incorrect.

A screenshot of a computer AI-generated content may be incorrect.Select these options

We can have PCBway assemble the whole PCB

A screenshot of a computer AI-generated content may be incorrect.

Then you will have to upload Bill of Material files, Centroid files
(CPL.txt) and assembly drawing optional).

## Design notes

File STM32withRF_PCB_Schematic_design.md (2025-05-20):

Chip used :- STM32WB55CEU6.

Important Online Note :-
<https://www.st.com/resource/en/application_note/an5165-how-to-develop-rf-hardware-using-stm32wb-microcontrollers-stmicroelectronics.pdf>

A diagram of a circuit board AI-generated content may be incorrect.{width="8.188888888888888in"
height="4.441666666666666in"}This is the reference :-

Use STM32CubeIDE to get more information about the Chip :-

A screenshot of a computer AI-generated content may be incorrect.{width="7.108333333333333in"
height="3.245138888888889in"}

A screenshot of a computer AI-generated content may be incorrect.{width="8.170833333333333in"
height="4.066666666666666in"}Here I have enabled I2C on PB8 and PB9
corresponding to Pin 5 and 6 respectively.

In Kicad, import the board STM32WB55CEUX.

Ground the Pins VSS5MP5, VSSRF and VSS.

A screen shot of a computer AI-generated content may be incorrect.{width="2.5085509623797027in"
height="1.7334831583552055in"}

As illustrated on the reference manual, the Pin VDDUSB, VDDA, VDD, VDD,
VDD and VBAT are connected to 3.3V power supply through bigger capacitor
(4.67uF) and smaller capacitors (100nF : local supply).

A screen shot of a graph AI-generated content may be incorrect.{width="7.9625in"
height="2.091666666666667in"}

For VDDRF, connect it to 100nF capacitor along with power supply

A screenshot of a computer AI-generated content may be incorrect.{width="2.316666666666667in"
height="2.4159722222222224in"}

We need Stepdown converter to step down voltage for lower voltage. For 8
MHz we use 2.2uH inductor and for 4MHz we use 10uF inductor. SMPSLX --
Switch Mode Power Supply

SMPSFB -- Switch Power Supply Feed Back

A screenshot of a computer AI-generated content may be incorrect.{width="6.501388888888889in"
height="2.433333333333333in"}

The low frequency oscillator(Crystal) is connected to Pin 2 and 3.

A screenshot of a computer AI-generated content may be incorrect.{width="2.591890857392826in"
height="2.608559711286089in"}

A screenshot of a computer AI-generated content may be incorrect.{width="4.900424321959755in"
height="2.591890857392826in"}The high frequency
oscillator(Crystal_GND24) are connected to Pin 24 and 25.

We can add resistor in HSC_IN to increase the longevity of oscillator.

A diagram of a circuit AI-generated content may be incorrect.{width="6.501388888888889in"
height="2.484027777777778in"}RF Section:-

We need low pass filter for 2.4GHz and 5GHz.

For that we need to create a footprint and symbol of DLF162500LT-5028A1.

A screenshot of a computer AI-generated content may be incorrect.{width="6.501388888888889in"
height="3.80625in"}From File, Add library\> DLF162500LT-5028A1

A screenshot of a computer AI-generated content may be incorrect.{width="6.501388888888889in"
height="3.454861111111111in"}Go to the Pin table and add pins.

Use the rectangle tool on the right side to draw the rectangle touching
the pins.A screen shot of a computer AI-generated content may be incorrect.{width="6.501388888888889in"
height="4.063194444444444in"}

Use the Text "T" tool to add the text label "2.4GHz- 2.5GHz".

Save the symbol. Now it's time to create the physical footprint of the
symbol.

Use this footprint editor to create the new footprint.A screenshot of a computer AI-generated content may be incorrect.{width="6.501388888888889in"
height="2.9659722222222222in"}

Go to file \> Add library and name your library.

Here the newly added library is STM32_RF_LowPassFilterFootPrint

A screenshot of a computer AI-generated content may be incorrect.{width="6.501388888888889in"
height="3.9569444444444444in"}

In the new library, add new Footprint and name it as Component name eg.
"DLF162500LT-5028A1"

This is the dimension of
[footprint](https://product.tdk.com/system/files/dam/doc/product/rf/rf/filter/catalog/rf_lpf_dlf162500lt-5028a1_en.pdf).

A blueprint of a diagram AI-generated content may be incorrect.

A screenshot of a phone AI-generated content may be incorrect.{width="6.501388888888889in"
height="3.509027777777778in"}Add pad from here.

According to the dimension, the centre of origin:-

X : ½ ( 0.275 + 0.45) + 0.25 = 0.6125.

Y : ½ (0.245 +0.21) = 0.2275

This is the position and dimensions of pad1 :-

A screenshot of a computer AI-generated content may be incorrect.{width="5.45in"
height="3.1930555555555555in"}

This is the position and dimensions of pad 3:-

A screenshot of a computer AI-generated content may be incorrect.{width="6.501388888888889in"
height="4.285416666666666in"}

This is the position and dimensions of pad 2:-

A screenshot of a computer AI-generated content may be incorrect.{width="4.527777777777778in"
height="2.9868055555555557in"}

This is the position and dimensions of pad 4:-

A screenshot of a computer AI-generated content may be incorrect.{width="5.383333333333334in"
height="3.5430555555555556in"}

Download 3D Model of symbol from A screenshot of a computer AI-generated content may be incorrect.{width="6.501388888888889in"
height="3.2395833333333335in"}ultralibrarian in .step format.

A screenshot of a computer AI-generated content may be incorrect.{width="6.501388888888889in"
height="3.9097222222222223in"}In Kicad go to footprint properties and
add the 3d model. Our pad aligns with physical pins.

A screen shot of a computer AI-generated content may be incorrect.{width="6.501388888888889in"
height="3.2534722222222223in"}With silkscreen layer selected, click
circle tool to add indicator for pin 1.

Using the symbol editor, assign newly created footprint to the symbol we
just created.

A screenshot of a computer AI-generated content may be incorrect.{width="6.501388888888889in"
height="3.4722222222222223in"}

Place newly created symbol to the schematic and connect to pin 1.A diagram of a circuit AI-generated content may be incorrect.{width="6.501388888888889in"
height="4.33125in"}

Add a Co-Axial connector.

A screenshot of a computer AI-generated content may be incorrect.{width="4.779166666666667in"
height="2.702777777777778in"}

A computer diagram of a circuit board AI-generated content may be incorrect.{width="6.501388888888889in"
height="3.841666666666667in"}This is our current progress.

Now, we need to add the programming interface.

The PA 13, PA 14 and PA3 can be used to program and debug the board.
Along with those pins NRST has to be low (0) for programming mode and
high (1) on normal mode.

A screenshot of a computer AI-generated content may be incorrect.{width="6.501388888888889in"
height="2.425in"}

Connect the tag connector "Conn_ARM_SWD_TagConnect_TC2030". Connect the
tag connector to respective pin as shown. For NRST( Reset) pin connect
it through 100nF capacitor at Pin 7.

A diagram of a circuit board AI-generated content may be incorrect.{width="6.501388888888889in"
height="4.0375in"}

PH3 is bootload pin and should 0 be on bootload. When the pin Switch is
not pressed, the PH3 is grounded but on pressed, the connection acts as
lowpass RC filter.

A diagram of a circuit AI-generated content may be incorrect.{width="5.583816710411199in"
height="3.058597987751531in"}

Add USB "USB_C_Receptacle_USB2.0_16P" and we are going to use pin 37 and
38.

A computer screen shot of a circuit board AI-generated content may be incorrect.{width="4.24375in"
height="2.86875in"}

Add a USB protector between the USB Connector and Pins.

A diagram of a circuit board AI-generated content may be incorrect.{width="6.501388888888889in"
height="2.941666666666667in"}

The D- pins and D+ pins are connected each other and then to Pins 1 and
3 respectively on the USB protector. The VBUS is connected to Pin 5. Pin
6 and 4 are connected to Pin 37 and 37 respectively on the STM32
Microcontroller.

The pull down resistors are tied on the Pin A5 and B5.

Convert 5V of VBUS to 3.3V using LDO voltage regulator.

Search LDO voltage regulator by putting requirement on mouser. Add a
voltage regulator "MIC5365-3.3YD5" to get 3.3V output.

A computer circuit board with many wires AI-generated content may be incorrect.{width="5.428472222222222in"
height="3.09375in"}

A diagram of a circuit AI-generated content may be incorrect.{width="6.501388888888889in"
height="3.113888888888889in"}Add a Peripheral connection on PA2 and PA2
using Generic 01\*04 Connector.

A screenshot of a computer AI-generated content may be incorrect.{width="7.738305993000875in"
height="2.6607141294838144in"}Use PA7 for PWM Output signal generation.

Add LED to Pin 16 (PA7) and add current limiting 220 Ohm resistor.

A screenshot of a computer AI-generated content may be incorrect.{width="4.47538823272091in"
height="1.6501432633420823in"}

A computer diagram of a circuit board AI-generated content may be incorrect.{width="8.00763888888889in"
height="5.25in"}Overall schematic :-

A computer screen shot of a computer program AI-generated content may be incorrect.{width="7.152083333333334in"
height="3.579861111111111in"}Run electric rule checker and make sure all
wirings are correct.

Add footprint to the capacitor.

{width="6.501388888888889in"
height="2.921527777777778in"}

Add footprint to all the components.

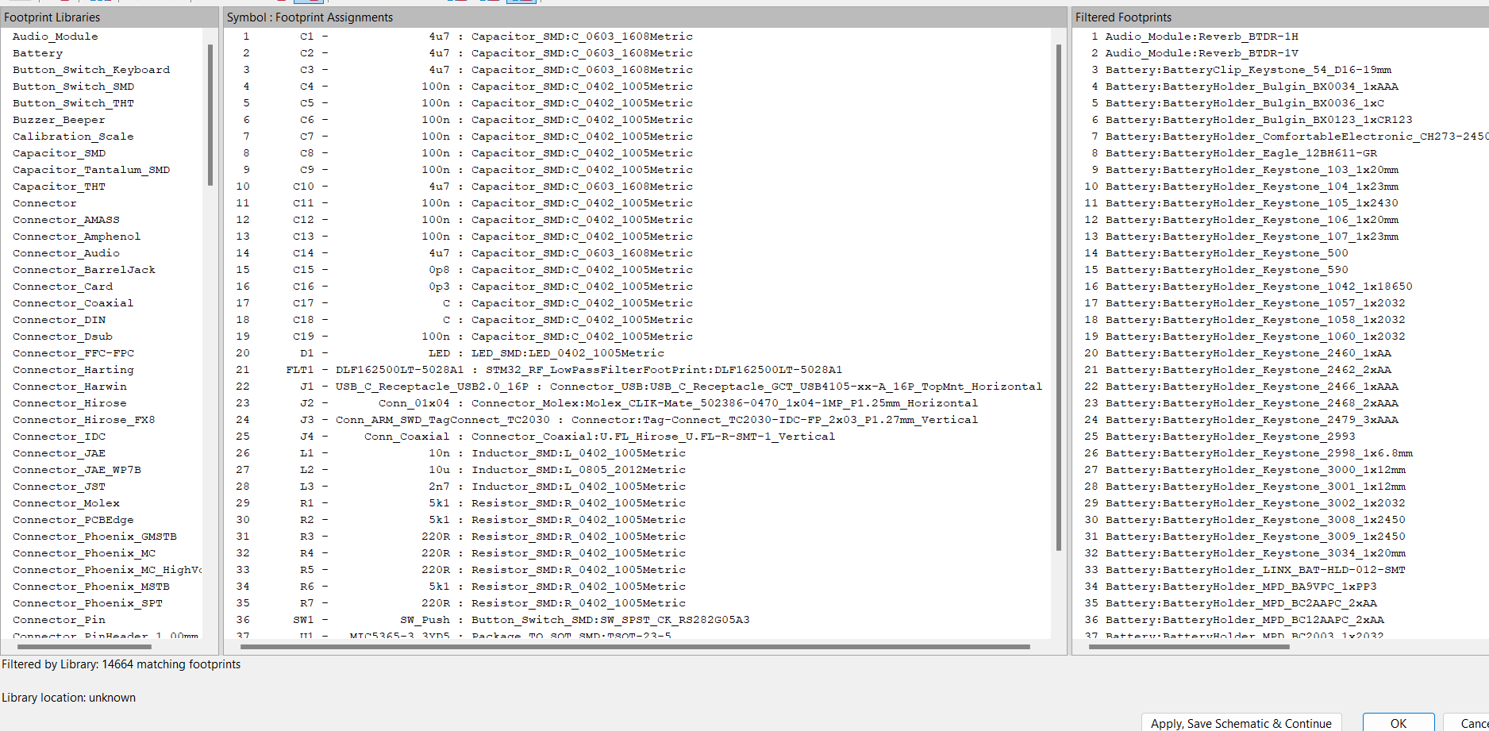
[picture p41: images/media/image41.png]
{width="6.501388888888889in"
height="3.191666666666667in"}

Create Bill of Materials for all the components.

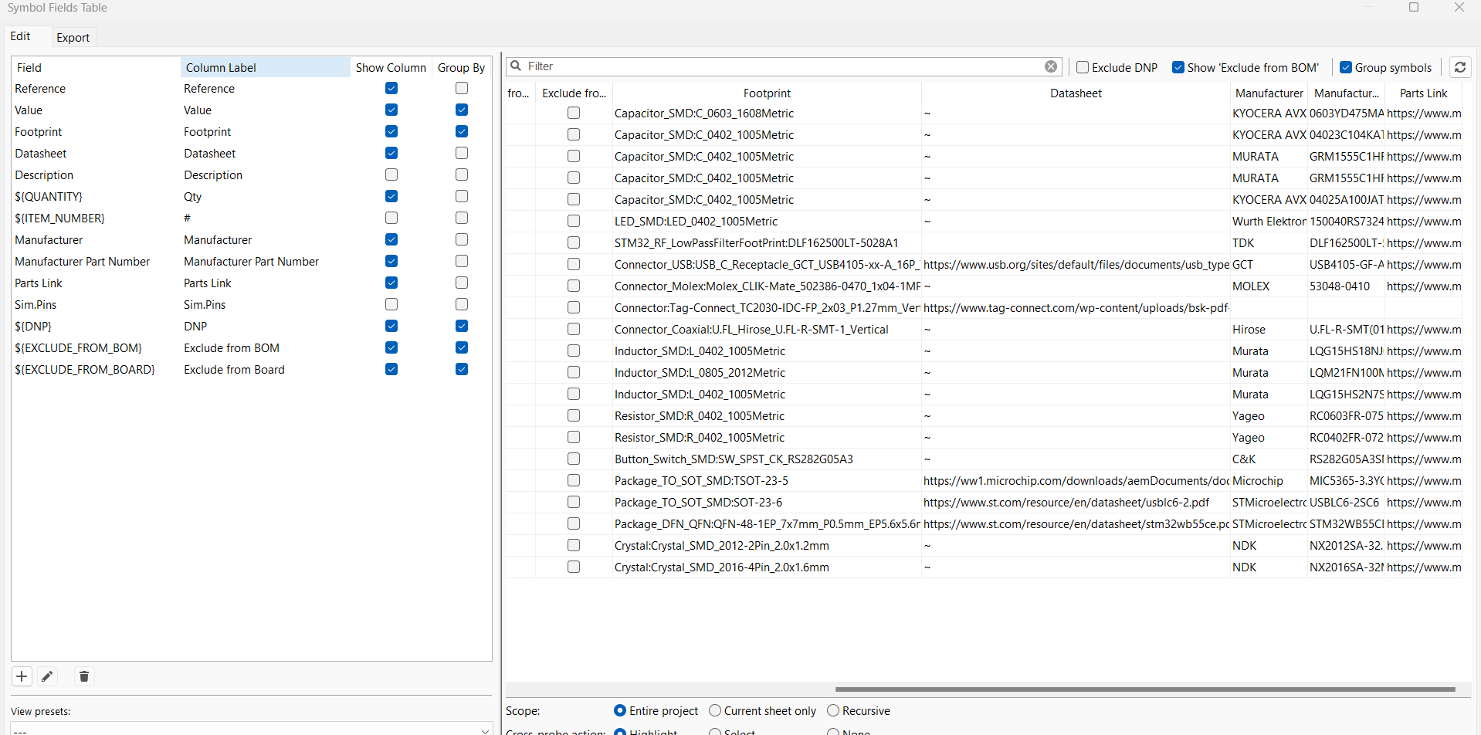
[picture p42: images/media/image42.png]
{width="6.501388888888889in"
height="3.2270833333333333in"}

Add netclass to group the components.

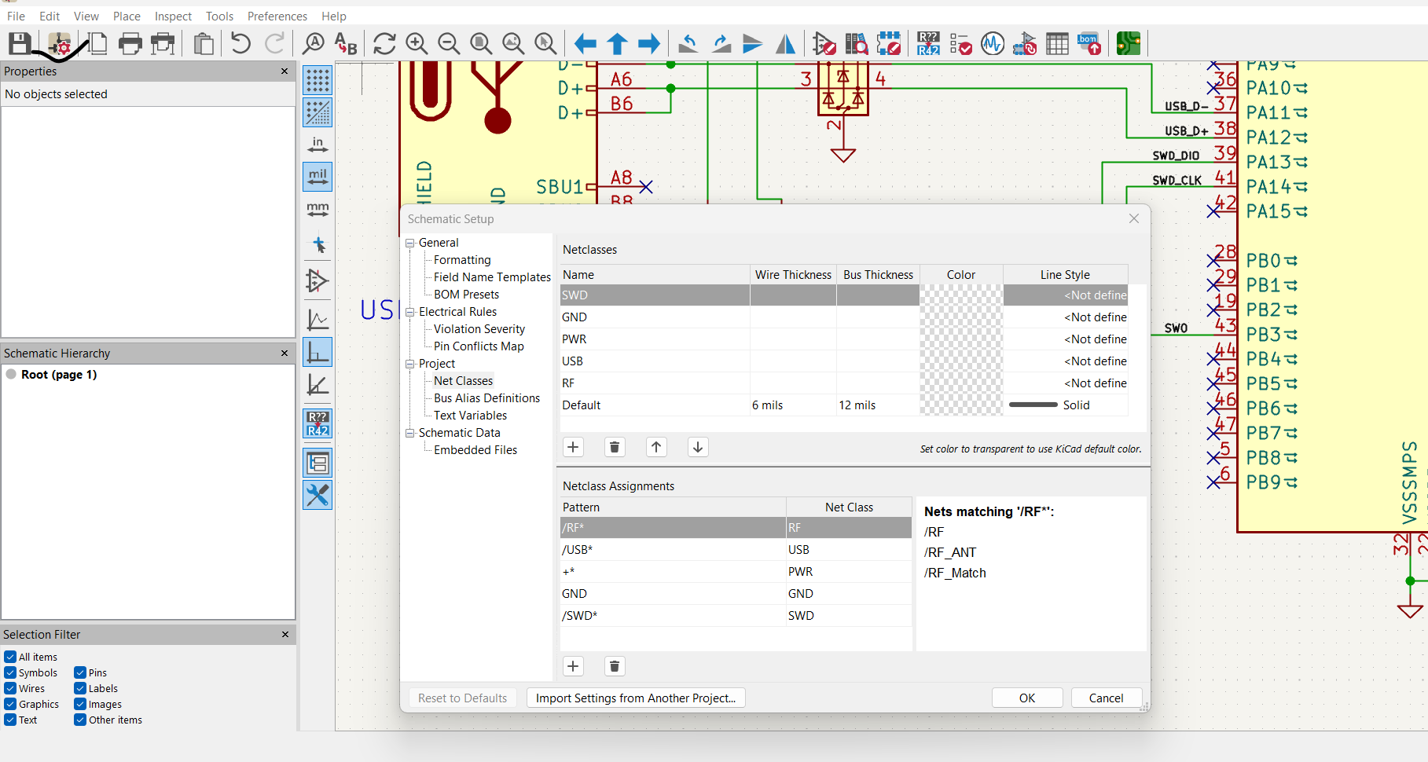
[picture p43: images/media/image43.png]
{width="6.501388888888889in"
height="3.470833333333333in"}

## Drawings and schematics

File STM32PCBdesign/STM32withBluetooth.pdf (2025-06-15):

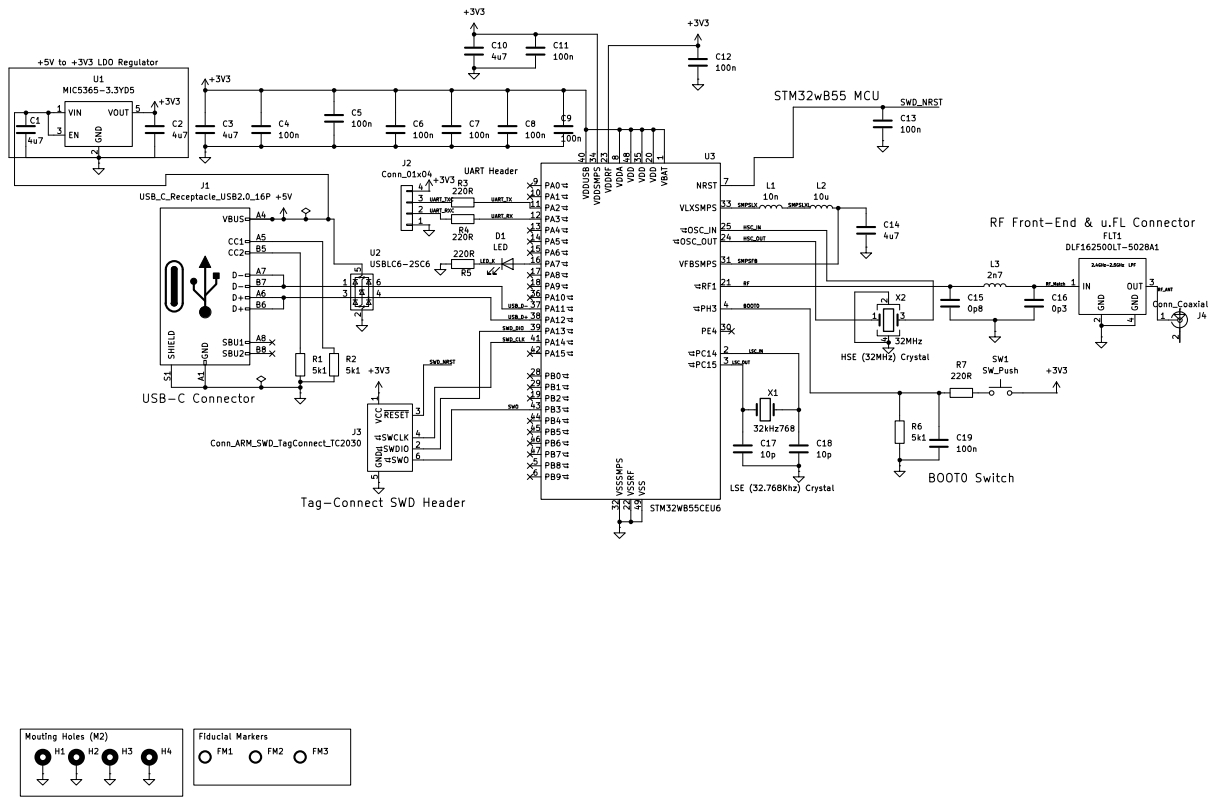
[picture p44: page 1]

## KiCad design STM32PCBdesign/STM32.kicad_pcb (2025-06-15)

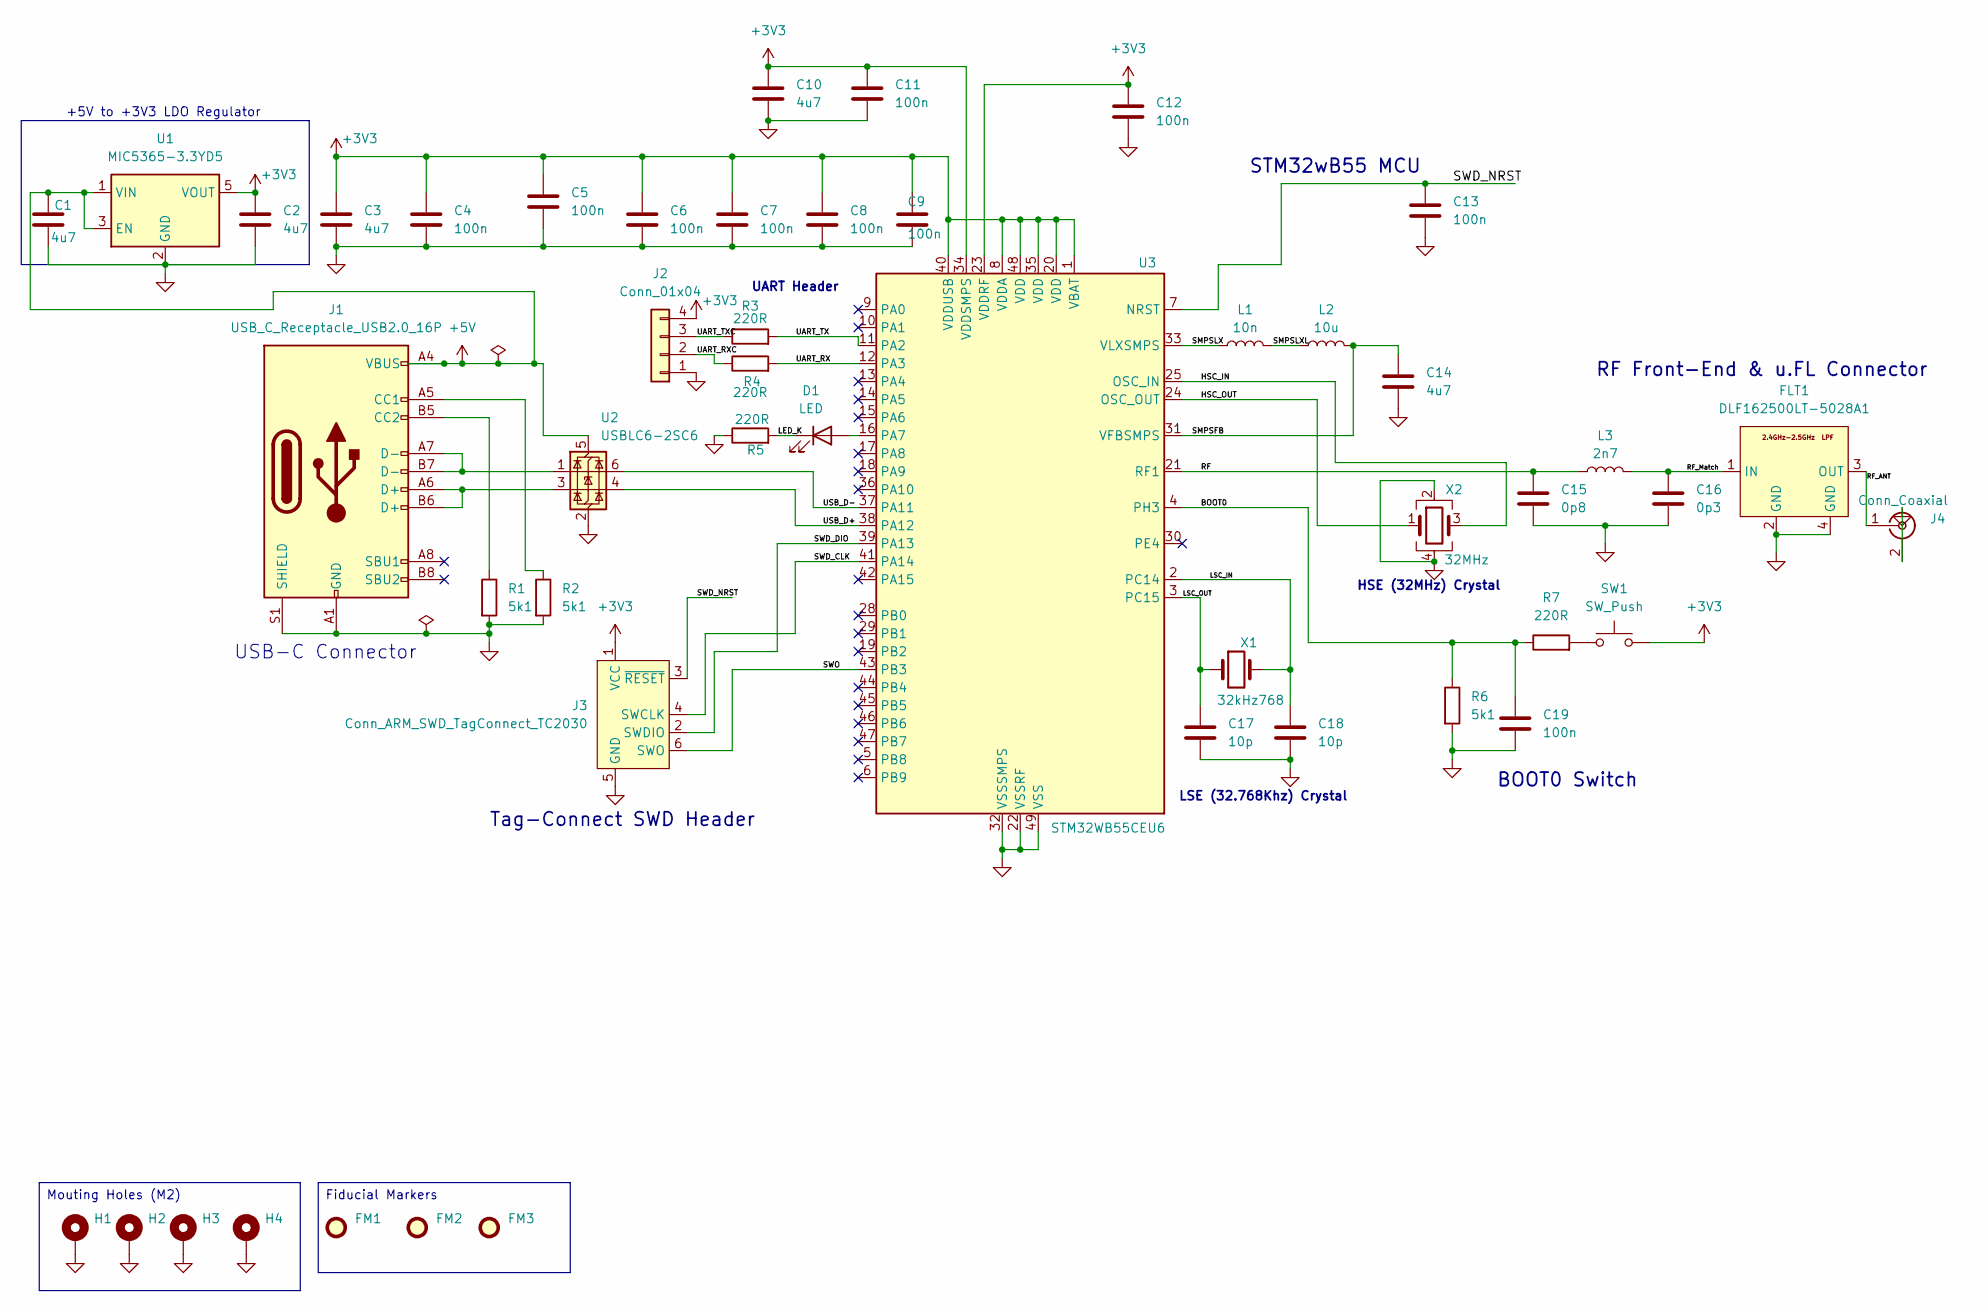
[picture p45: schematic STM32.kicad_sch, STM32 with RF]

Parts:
C1, C2, C3, C10, C14: 4u7; C_0603_1608Metric; Manufacturer Part Number 0603YD475MAT2A
C4, C5, C6, C7, C8, C9, C11, C12, C13, C19: 100n; C_0402_1005Metric; Manufacturer Part Number 04023C104KAT2A
C15: 0p8; C_0402_1005Metric; Manufacturer Part Number GRM1555C1HR80BA01D
C16: 0p3; C_0402_1005Metric; Manufacturer Part Number GRM1555C1HR30WA01D
C17, C18: 10p; C_0402_1005Metric; Manufacturer Part Number 04025A100JAT4A
D1: LED; LED_0402_1005Metric; Manufacturer Part Number 150040RS73240
FLT1: DLF162500LT-5028A1; Manufacturer Part Number DLF162500LT-5028A1
FM1, FM2, FM3: Fiducial; Fiducial_1mm_Mask2mm
H1, H2, H3, H4: MountingHole_Pad; MountingHole_2.2mm_M2_Pad_Via
J1: USB_C_Receptacle_USB2.0_16P; USB_C_Receptacle_GCT_USB4105-xx-A_16P_TopMnt_Horizontal; Manufacturer Part Number USB4105-GF-A
J2: Conn_01x04; Molex_CLIK-Mate_502386-0470_1x04-1MP_P1.25mm_Horizontal; Manufacturer Part Number 53048-0410
J3: Conn_ARM_SWD_TagConnect_TC2030; Tag-Connect_TC2030-IDC-FP_2x03_P1.27mm_Vertical
J4: Conn_Coaxial; U.FL_Hirose_U.FL-R-SMT-1_Vertical; Manufacturer Part Number U.FL-R-SMT(01)
L1: 10n; L_0402_1005Metric; Manufacturer Part Number LQG15HS18NJ02D
L2: 10u; L_0805_2012Metric; Manufacturer Part Number LQM21FN100M70L
L3: 2n7; L_0402_1005Metric; Manufacturer Part Number LQG15HS2N7S02D
R1, R2, R6: 5k1; R_0402_1005Metric; Manufacturer Part Number RC0603FR-075K1L
R3, R4, R5, R7: 220R; R_0402_1005Metric; Manufacturer Part Number RC0402FR-07221RL
SW1: SW_Push; SW_SPST_CK_RS282G05A3; Manufacturer Part Number RS282G05A3SMRT
U1: MIC5365-3.3YD5; TSOT-23-5; Manufacturer Part Number MIC5365-3.3YC5-TR
U2: USBLC6-2SC6; SOT-23-6; Manufacturer Part Number USBLC6-2SC6
U3: STM32WB55CEU6; QFN-48-1EP_7x7mm_P0.5mm_EP5.6x5.6mm; Manufacturer Part Number STM32WB55CEU6
X1: 32kHz768; Crystal_SMD_2012-2Pin_2.0x1.2mm; Manufacturer Part Number NX2012SA-32.768K-STD-MUB-1
X2: 32MHz; Crystal_SMD_2016-4Pin_2.0x1.6mm; Manufacturer Part Number NX2016SA-32M-EXS00A-CS06465

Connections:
+3V3: C2.1, C3.1, C4.1, C5.1, C6.1, C7.1, C8.1, C9.1, C10.1, C11.1, C12.1, J2.4, J3.1 (VCC), SW1.2, U1.5 (VOUT), U3.1 (VBAT), U3.8 (VDDA), U3.20 (VDD), U3.23 (VDDRF), U3.34 (VDDSMPS), U3.35 (VDD), U3.40 (VDDUSB), U3.48 (VDD)
+5V: C1.1, J1.A4 (VBUS), J1.A9 (VBUS), J1.B4 (VBUS), J1.B9 (VBUS), U1.1 (VIN), U1.3 (EN), U2.5 (VBUS)
/BOOT0: C19.1, R6.1, R7.1, U3.4 (PH3)
/HSC_IN: U3.25 (OSC_IN), X2.3
/HSC_OUT: U3.24 (OSC_OUT), X2.1
/LED_K: D1.1 (K), R5.2
/LSC_IN: C18.1, U3.2 (PC14), X1.2
/LSC_OUT: C17.1, U3.3 (PC15), X1.1
/RF: C15.1, L3.1, U3.21 (RF1)
/RF_ANT: FLT1.3 (OUT), J4.1 (In)
/RF_Match: C16.1, FLT1.1 (IN), L3.2
/SMPSFB: C14.1, L2.2, U3.31 (VFBSMPS)
/SMPSLX: L1.1, U3.33 (VLXSMPS)
/SMPSLXL: L1.2, L2.1
/SWD_CLK: J3.4 (SWCLK), U3.41 (PA14)
/SWD_DIO: J3.2 (SWDIO), U3.39 (PA13)
/SWD_NRST: C13.1, J3.3 (~RESET), U3.7 (NRST)
/SWO: J3.6 (SWO), U3.43 (PB3)
/UART_RX: R4.2, U3.12 (PA3)
/UART_RXC: J2.2, R4.1
/UART_TX: R3.2, U3.11 (PA2)
/UART_TXC: J2.3, R3.1
/USB_D+: U2.4 (I/O2), U3.38 (PA12)
/USB_D-: U2.6 (I/O1), U3.37 (PA11)
GND: C1.2, C2.2, C3.2, C4.2, C5.2, C6.2, C7.2, C8.2, C9.2, C10.2, C11.2, C12.2, C13.2, C14.2, C15.2, C16.2, C17.2, C18.2, C19.2, FLT1.2 (GND), FLT1.4 (GND), H1.1, H2.1, H3.1, H4.1, J1.A1 (GND), J1.A12 (GND), J1.B1 (GND), J1.B12 (GND), J1.S1 (SHIELD), J2.1, J3.5 (GND), J4.2 (Ext), R1.2, R2.2, R5.1, R6.2, U1.2 (GND), U2.2 (GND), U3.22 (VSSRF), U3.32 (VSSSMPS), U3.49 (VSS), X2.2, X2.4
unnamed: D1.2 (A), U3.16 (PA7)
unnamed: J1.A5 (CC1), R2.1
unnamed: J1.B5 (CC2), R1.1
unnamed: J1.A6 (D+), J1.B6 (D+), U2.3 (I/O2)
unnamed: J1.A7 (D-), J1.B7 (D-), U2.1 (I/O1)
unnamed: R7.2, SW1.1

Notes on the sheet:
BOOT0 Switch
RF Front-End & u.FL Connector
UART Header
+5V to +3V3 LDO Regulator
STM32wB55 MCU
Tag-Connect SWD Header
HSE (32MHz) Crystal
USB-C Connector
LSE (32.768Khz) Crystal
Fiducial Markers
Mouting Holes (M2)

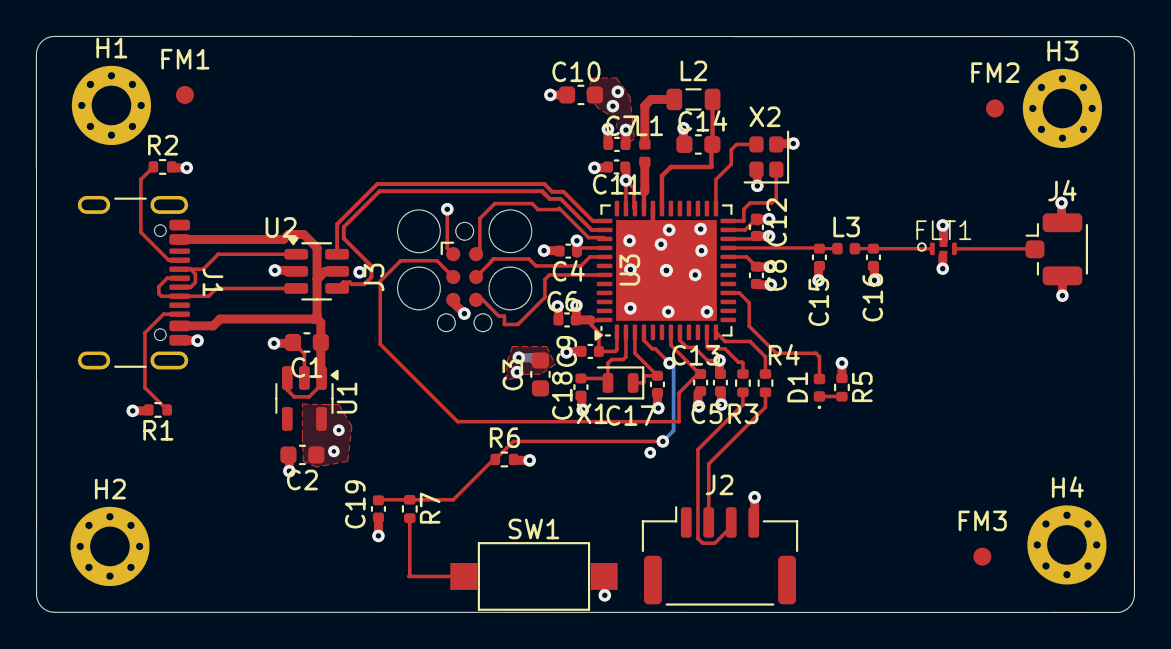
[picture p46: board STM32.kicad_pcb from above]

Board: 4 copper layers, 61.0 x 32.0 mm, 48 parts (0 on the bottom side), 31 nets.

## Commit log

2025-05-20 Update and rename STM32withRF_PCB_design.md to STM32withRF_PCB_Schematic_design.md
2025-06-15 PCB design and Schematics
    [STM32-B_Cu.gbr, STM32-B_Mask.gbr, STM32-Edge_Cuts.gbr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]
2025-06-15 Final PCB design walkthrough
